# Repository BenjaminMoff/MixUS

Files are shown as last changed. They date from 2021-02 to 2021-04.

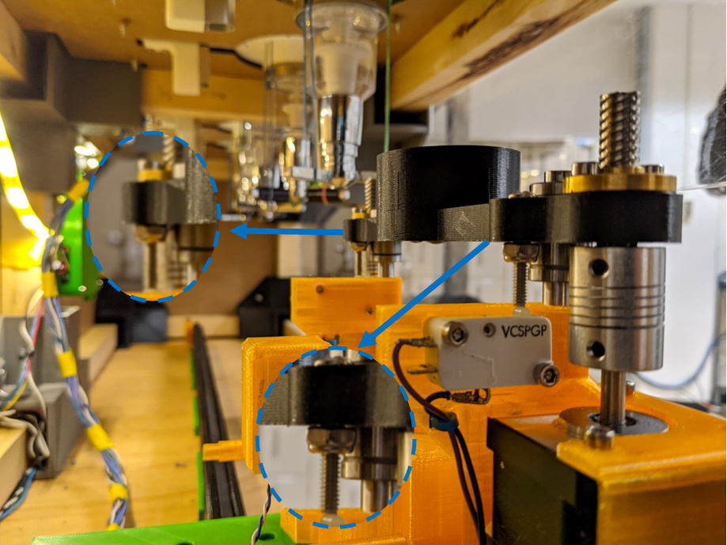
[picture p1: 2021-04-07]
Media Wiki/XYZ Assembly/Assembly Picture/Z_Pusher_Adjustement_Screw.png

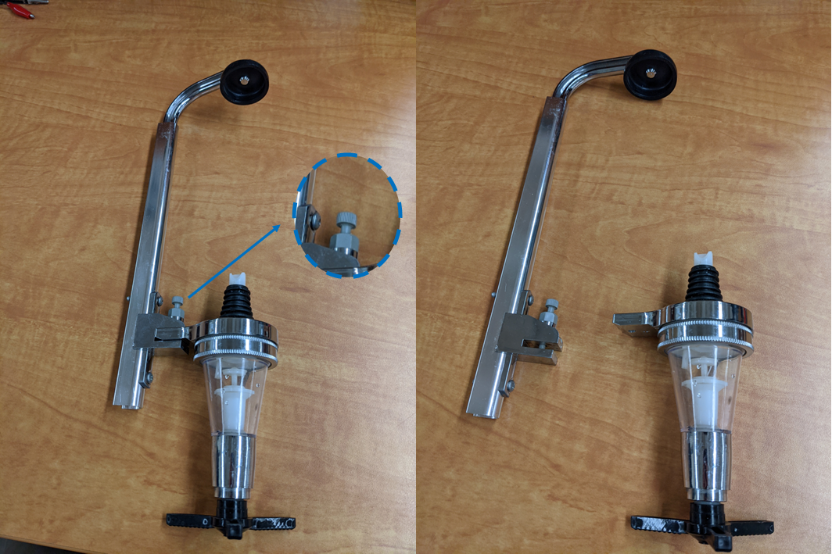
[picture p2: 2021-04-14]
Media Wiki/Frame Assembly/Assembly picture/Dispenser_1.png

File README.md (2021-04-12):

# MixUS
<p align="center">
  animated
  animated
  
  animated
</p>

From left to right : Laurent Tétreault, Yohan Bélanger, Félix Richard, Benjamin Moffett & Raphaël Cloutier
## Software License GNU GPL
MixUS is an open source project that uses the GNU GPL v3 license. This license is used since PyQt5, the framework that the app is built on, is also GNU GPL v3.

1. Anyone can copy, modify and distribute this software.
2. You have to include the license and copyright notice with each and every distribution.
3. You can use this software privately.
4. You can use this software for commercial purposes.
5. If you build your business solely from this code, you need to open-source the whole code base.
6. If you modify it, you have to indicate changes made to the code.
7. Any modifications of this code base MUST be distributed with the same license, GPLv3.
8. This software is provided without warranty.
9. The software author or license can not be held liable for any damages inflicted by the software.

More information about this license can be found [here](https://gist.github.com/kn9ts/cbe95340d29fc1aaeaa5dd5c059d2e60)

## Material License CC BY-SA
MixUS uses cads found in the [Open Build catalog](https://openbuildspartstore.com/). Thus, the material license for this project is the Creative Commons Attribution-ShareAlike 4.0 International (CC BY-SA). 
Under this license, you are free to:
- Share: copy and redistribute the material in any medium or format
- Adapt: remix, transform, and build upon the material for any purpose, even commercially.

Under the following terms:
- Attribution: You must give appropriate credit, provide a link to the license, and indicate if changes were made. You may do so in any reasonable manner, but not in any way that suggests the licensor endorses you or your use.
- ShareAlike: If you remix, transform, or build upon the material, you must distribute your contributions under the same license as the original.

More information about this license can be found [here](https://creativecommons.org/licenses/by-sa/4.0/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)

## Mechanical Assembly
All the information for mechanical assembly can be found in [this wiki](https://github.com/BenjaminMoff/MixUS/wiki).
## Software

### Raspberry Pi Setup
If you chose to use a Raspberry Pi, you can run [this file](https://github.com/BenjaminMoff/MixUS/blob/main/configuration/PiConfig.sh) to automagically download Python, compile it, and get all the required packages.

If you are using the same 7" touch screen that we are (see the bom for the exact screen), you need to change the following in the Raspberry Pi's config.txt file:
- max_usb_curren=1
- hdmi_force_hotplug=1
- config_hdmi_boost=7
- hdmi_group=2
- hdmi_mode=87
- hdmi_drive=1
- display_rotate=0
- hdmi_cvt 1024 600 60 6 0 0 0

### Windows Setup
If you chose to use a Windows computer, you need to have a version of Python 3 installed. Then, you can run [this file](https://github.com/BenjaminMoff/MixUS/blob/main/configuration/Pythonconfig.bat) to automagically download the required packages.

The Windows version of the app cannot support the detection of the cup since it is done using a limit switch connected to a Raspberry Pi.

### Change the database
The app uses a database to remember all the drinks you like and the bottles you have. You can add more drinks to the database by running, in the terminal from MixUS/code/, this command: 
- Windows: py DrinkDatabaseUpdater.py
- Raspbian: python3 DrinkDatabaseUpdater.py

### Run MixUS
To run the application, you need to run the following command in the terminal from MixUS/code/:
- Windows: py Mixus.py
- Raspbian: python3 Mixus.py

### Documentation
The entire documentation for the code can be found [here](https://htmlpreview.github.io/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).

## Special thanks to
Société des Alcools du Québec for providing the pictures used in the app. All of the pictures are their property and shall not be used for any other purpose other than recreating this project.

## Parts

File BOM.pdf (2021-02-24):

Mecanic BOM: 100XXX
No | Piece | Description
100001 | SUPPORTROUEY | Printed support of the y wheel
100002 | M 5X16MM SCREW | M5 X16 mm screw
100003 | 608Z BALL BEARING | 608ZZ ball bearing
100004 | M5 NUT | M5 nut
100005 | SUPPORTMOTEURZ | Printed support of the z motor
100006 | NEMA17 | Stepper motor NEMA 17
100007 | 5T08MM COUPLER | 5T 08 mm coupler
100008 | LIMITSWITCH | Limit switch
100009 | LEADSCREW | Lead screw
100010 | 8MM ROD | 8mm rod
100011 | M3 X 12MM SCREW | m3 X 12mm screw
100012 | M3 INSERT | M3 insert
100013 | IDLERX_PLATE | Idlerx plate
100014 | MOTOX_PLATE | Motox plate
100015 | GT2 MOTOR PULLEY | Gt2 Motor pulley
100016 | POULIE | Pulley
100017 | 20X40 EXTRUSION | 20x40cm printed extrude
100018 | CARRIAGEX | Carriage of the x motor
100019 | V-SLOT WHEEL | v-slot wheel
100020 | 6-32 X 1'' SCREW | 6-32 X 1'' screw
100021 | 6-32 LOCKNUT | 6-32 locknut
100022 | RAILY | Rail for the y movement
100023 | SPACER | Spacer
100024 | SUPPORTVERRE | Printed glass support
100025 | CHARIOT V2 | Printed cart for the glass
100026 | RAIL | Printed rail for the z movement
100026 | MIDDLE MODDED EXTRUSION | Printed extrusion in center
100026 | MODDED EXTRUSION MOTORSIDE | Printed extrusion on motor side
100026 | MODDED EXTRUSION PULLEYSIDE | Printed extrusion on pulley side
100026 | PUSHER | Pusher
100026 | LEADSCREW NUT | Leadscrew nut
100026 | LM8 UU | LM8UU

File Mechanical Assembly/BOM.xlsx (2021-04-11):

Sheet: V1
Mecanic BOM: 100XXX
No | Piece | Description
100001 | SUPPORTROUEY | Printed support of the y wheel
100002 | M 5X16MM SCREW | M5 X16 mm screw
100003 | 608Z BALL BEARING | 608ZZ ball bearing
100004 | M5 NUT | M5 nut
100005 | SUPPORTMOTEURZ | Printed support of the z motor
100006 | NEMA17 | Stepper motor NEMA 17
100007 | 5T08MM COUPLER | 5T 08 mm coupler
100008 | LIMITSWITCH | Limit switch
100009 | LEADSCREW | Lead screw
100010 | 8MM ROD | 8mm rod
100011 | M3 X 12MM SCREW | m3 X 12mm screw
100012 | M3 INSERT | M3 insert
100013 | IDLERX_PLATE | Idlerx plate
100014 | MOTOX_PLATE | Motox plate
100015 | GT2 MOTOR PULLEY | Gt2 Motor pulley
100016 | POULIE | Pulley
100017 | 20X40 EXTRUSION | 20x40cm printed extrude
100018 | CARRIAGEX | Carriage of the x motor
100019 | V-SLOT WHEEL | v-slot wheel
100020 | 6-32 X 1'' SCREW | 6-32 X 1'' screw
100021 | 6-32 LOCKNUT | 6-32 locknut
100022 | RAILY | Rail for the y movement
100023 | SPACER | Spacer
100024 | SUPPORTVERRE | Printed glass support
100025 | CHARIOT V2 | Printed cart for the glass
100026 | RAIL | Printed rail for the z movement
100026 | MIDDLE MODDED EXTRUSION | Printed extrusion in center
100026 | MODDED EXTRUSION MOTORSIDE | Printed extrusion on motor side
100026 | MODDED EXTRUSION PULLEYSIDE | Printed extrusion on pulley side
100026 | PUSHER | Pusher
100026 | LEADSCREW NUT | Leadscrew nut
100026 | LM8 UU | LM8UU

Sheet: V2
Printed parts |  |  |  |  |  | Fasteners
Section | Component | Configuration | Qty | Printing support |  | Section | Component | Qty | CAD Link | Where to buy
X Axis | X_Bracket_Wire | Default | 1 | No |  | Inserts | M2.5x3.4mm_insert | 20 | McMaster (https://www.mcmaster.com/94180A321/~)
 | X_Carriage | Default | 1 | Touching build plate only |  |  | M3x6mm_insert | 150 | GrabCAD (https://grabcad.com/library/fitsco-heatfit-range-brass-threaded-insert-for-plastic-1/details?folder_id=1381689) | Amazon.ca (https://www.amazon.ca/gp/product/B087N4LVD1/ref=ppx_yo_dt_b_asin_title_o00_s02?ie=UTF8&psc=1)
 | X_Idler_plate | Default | 1 | No |  | Nuts | 6_32_locknut | 16 | McMaster (https://www.mcmaster.com/90631A007/)
 | X_Motor_plate | Default | 1 | No |  |  | M5_Nut | 3 | McMaster (https://www.mcmaster.com/90591A260/~)
 | X_V_Wheel_spacer | Default | 4 | No |  |  | 0,1875po_Nut | 28 | N/A | renodepot.com (https://www.renodepot.com/fr/boulon-de-poele-63867995)
Y Axis | Y_Carriage | Default | 1 | No |  | Screws | 6_32_screw | 16 | McMaster (https://www.mcmaster.com/91772A153/~)
 | Y_Pinion | Default | 1 | No |  |  | M2.5x6mm_screw | 20 | McMaster
 | Y_rack | Default | 1 | No |  |  | M3x12mm_screw | 150 | McMaster
 | Y_rail | Default | 1 | No |  |  | M5x16mm_screw | 3 | McMaster
 | Y_Support_rail | Default | 1 | Yes |  |  | 0,1875x0,5po_Screw | 28 | N/A | renodepot.com (https://www.renodepot.com/fr/boulon-de-poele-63867995)
 | Y_Glass_holder | Default | 1 | Yes |  |  | No6x1,25po_Wood_Screw | 78 | McMaster (https://www.mcmaster.com/90610A719/)
 | Y_Extern_slider_support | Default | 1 | No |  |  | No12x1,25po_Wood_Screw | 24 | McMaster (https://www.mcmaster.com/92470A298/)
 | Y_Glass_Holder_Slider | Default | 1 | No
 | Y_Glass_Holder_Rod_Stopper | Default | 2 | No
 | Y_Glass_Holder_Rod | Default | 2 | No
 | Y_Switch_Bracket | Default | 1 | No
 | Y_Wheel_bracket | Default | 1 | Touching build plate only
 |  | Symmetry | 1 |  |  | Electronic
Z Axis | Z_Motor_Bracket | Default | 1 | Touching build plate only
 |  | Symmetry | 1 |  |  | Section | Component | Qty | CAD Link | Where to buy
 | Z_Pusher | Default | 1 | No |  | Proto PCB | 4x6cm_ProtoBoard | 1 | GrabCAD (https://grabcad.com/library/prototyping-breadboard-1) | Amazon.ca (https://www.amazon.ca/-/fr/Eiechip%C2%AE-prototype-universel-circuit-%C3%A9lectronique/dp/B07MTBNX8F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)
2040 printable extrusion | 2040_Printable_extrusion | Center | 3 | Yes | https://openbuilds.com/ |  | Extra_long_male_header_pin | 22 | N/A | Adafruit.com (https://www.adafruit.com/product/400)
 |  | Side | 2 |  |  | X, Y, Z Axis | LimitSwitch | 5 | GrabCAD (https://grabcad.com/library/limit-switch-6) | Amazon.ca (https://www.amazon.ca/Twidec-Switch-Roller-Arduino-V-156-1C25/dp/B07NVD5LGM)
 | 2040_Connector_Extrusion | M2.5 Slot | 8 | No |  |  | Nema17 | 4 | GrabCAD (https://grabcad.com/library/nema-17-stepper-motor-27) | Amazon.ca (https://www.amazon.ca/-/fr/SIMAX3D-Moteur-phases-imprimante-extrudeuse/dp/B0857489JD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)
 |  | M3 Top Slot | 4 | No |  | Wiring | Wire 22awg (Limit switch cup,Z) (200mm) | 6 | N/A | N/A
 |  | M3 slot | 8 | No |  |  | Wire 22awg (1m) | 26 | N/A | N/A
Rambo case | Rambo_Case_Top | Default | 1 | No |  |  | Wire 22 awg (1.5m) (extension to Pi) | 2 | N/A | N/A
 | Rambo_Case_Bottom | Default | 1 | Yes |  |  | Male dupont connector pin | 26 | N/A | Amazon.ca
Bottle Supports | BottleSup_Adapter | Default | 6 | Yes |  |  | Male dupont connector socket | 24 | N/A
 | BottleSup_Lock | Default | 24 | No |  |  | Female dupont connector pin | 2 | N/A
 | BottleSup_Removable_Plate_A | Default | 6 | Yes |  | Control | 7'' touch screen | 1 | N/A | Amazon.ca (https://www.amazon.ca/-/fr/Longruner-Raspberry-tactile-syst%C3%A8mes-protection/dp/B07RZZW8W1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)
 | BottleSup_Removable_Plate_B | Default | 6 | Yes |  |  | Raspberry pi 4 | 1 | N/A | CanaKit.com (https://www.canakit.com/raspberry-pi-4-2gb.html?cid=cad&src=raspberrypi)
Frame | Frame_Bottom_Center_Beam_Bracket | Plexi side | 1 | No |  |  | Rambo_board | 1 | GrabCAD (https://grabcad.com/library/reprap-electo-rambo-3d-printer-board-1-3-1) | Ultimachine (https://ultimachine.com/products/rambo-1-3)
 |  | Wood side | 1 | No |  |  | 40x40x10_DC_Fan | 1 | GrabCAD (https://grabcad.com/library/40mm-dc-fan-1) | Amazon.ca (https://www.amazon.ca/-/fr/Noctua-Ventilateur-silencieux-NF-A4x10-FLX/dp/B009NQLT0M)
 | Frame_Top_Center_Beam_Bracket | Plexi side | 1 | No
 |  | Wood side | 1 | No
 | Frame_Corner_Plexi_Side | Default | 1 | No
 |  | Symmetry | 1 | No
 | Frame_Corner_Wood_Side | Default | 1 | No |  | Others
 |  | Symmetry | 1 | No
 |  |  |  |  |  | Section | Part | Qty | CAD Link | Where to buy
 |  |  |  |  |  | Z Axis | 5_to_8_mm_coupler | 2 | GrabCAD (https://grabcad.com/library/nema-17-coupler-1) | Spool3D.ca (https://spool3d.ca/flexible-coupling-5mm-to-8mm/)
wood + acrylic |  |  |  |  |  |  | 8mm_38.5mm_leadscrew | 2 | GrabCAD (https://grabcad.com/library/8mm-lead-screw-with-nut-1) | Spool3D.ca (https://spool3d.ca/lead-screw-8mm-2mm-pitch-8mm-lead/)
 |  |  |  |  |  |  | 8mm_leadscrew_nut | 2 | GrabCAD (https://grabcad.com/library/8mm-lead-screw-with-nut-1) | Spool3D.ca (https://spool3d.ca/t8-lead-screw-nut/)
 | Specifications | qty | Where to buy |  |  |  | 8mm_50mm_rod | 2 | N/A | Spool3D.ca (https://spool3d.ca/straight-rod-8mm/)
2po x 2po wood beam | 532.4 mm | 8 | renodepot.com (https://www.renodepot.com/fr/pin-blanc-2-po-x-2-po-x-8-pi-8670092) |  |  |  | LM8UU_linear_bearing | 2 | GrabCAD (https://grabcad.com/library/lm8uu-others-1~) | Spool3D.ca (https://spool3d.ca/lm8uu-linear-bearing/)
 | 227 mm | 6 |  |  |  |  | Rubber band (wall = 1mm, width = 1.2 mm, flat length = 65 mm) | 18 | N/A | Bureauengros.com (https://www.bureauengros.com/products/13552-fr-staples-bandes-elastiques-economiques-tailles-et-couleurs-variees)
 | 250 mm | 5 |  |  |  | X Axis | GT2_pulley | 1 | GrabCAD (https://grabcad.com/library/pulley-gt2-20t-b5-1) | Spool3D.ca (https://spool3d.ca/20-tooth-gt2-pulley-for-hnbr-high-temperature-belt)
2 ft x 4 ft x 1/4 po masonite | N/A | 6 | renodepot.com (https://www.renodepot.com/fr/panneau-de-masonite-afa-regulier-1-4-x-2-x-4-75215204-8914017) |  |  |  | Idler_pulley | 1 | N/A | SeeMeCNC (https://www.seemecnc.com/collections/parts-accessories/products/r4-idler-bearing-cover-9-pack)
 |  |  |  |  |  |  | 608zz_ball_bearing | 2 | N/A | Spool3D.ca (https://spool3d.ca/608zz-bearing/~)
 |  |  |  |  |  |  | Vslot_wheel | 4 | N/A | Spool3D.ca (https://spool3d.ca/solid-v-slot-wheel-pom/)
410mm x 620 mm x 3.3 mm acrylic | N/A | 2 | renodepot.com (https://www.renodepot.com/fr/em-plastic-panneau-en-acrylique-3-mm-18-x-36-blanc-49085-55375025) |  |  | Others | Dispenser | 6 | GrabCAD (https://grabcad.com/library/shot-dispenser-1) | Amazon.ca (https://www.amazon.ca/-/fr/Distributeur-rotatif-liqueur-bouteilles-FTA1814/dp/B005BYWYHW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)
 |  |  |  |  |  |  | Red_cup | 1 | N/A | Costco (https://www.costco.ca/kirkland-signature-the-big-red-cup-heavyweight-18-oz.-plastic-cold-cups%2C-240-count.product.100484805.html)
 |  |  |  |  |  | Y Axis | 8x3mm_magnet | 8 | N/A | Amazon.ca (https://www.amazon.ca/Wukong-Magnets-Magnetic-Circular-magnet-108/dp/B07GTM383S)

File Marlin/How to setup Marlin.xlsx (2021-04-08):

If you don't have the same hardware (stepper motor, stepper driver, belt, etc.), use this excel sheet to calculate your specific step/mm for each axis
Informations about your specific setup are highlight in blue. Where you can find these informations are highlight in yellow. Informations that you need to put in your Marlin configuration are highlight in green
Information | Where to find ? | Value
Number of step per revolution | Stepper data sheet | 200
Stepper driver microstep (in fraction) | Stepper driver data sheet | 0.0625
 |  |  |  |  | To update Marlin :
X Axis |  |  | step/mm X : | 80 | 1. Open « configuration.h » in your Marlin folder
Belt pitch (mm) | Belt data sheet | 2 |  |  | 2. Seach (ctrl-F) « DEFAULT_AXIS_STEPS_PER_UNIT »
Pulley number of teeth | Count it or data sheet | 20 |  |  | 3. Replace « step X », « step Y » and « step Z » from the picture below with your calulate value (green)
Y Axis |  |  | step/mm Y : | 21.22065908
Modulus gear | CAD | 3
Number of teeth of the gear | CAD | 16
Pitch Y |  | 9.425
Z Axis
Leadscrew pitch (mm) | leadscrew data sheet | 8 | step/mm Z : | 400

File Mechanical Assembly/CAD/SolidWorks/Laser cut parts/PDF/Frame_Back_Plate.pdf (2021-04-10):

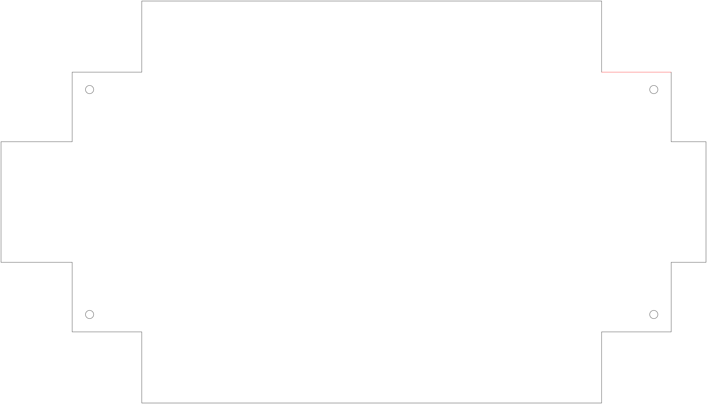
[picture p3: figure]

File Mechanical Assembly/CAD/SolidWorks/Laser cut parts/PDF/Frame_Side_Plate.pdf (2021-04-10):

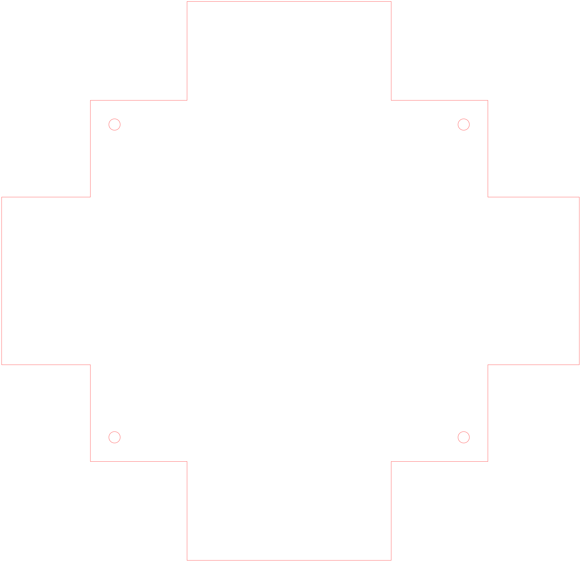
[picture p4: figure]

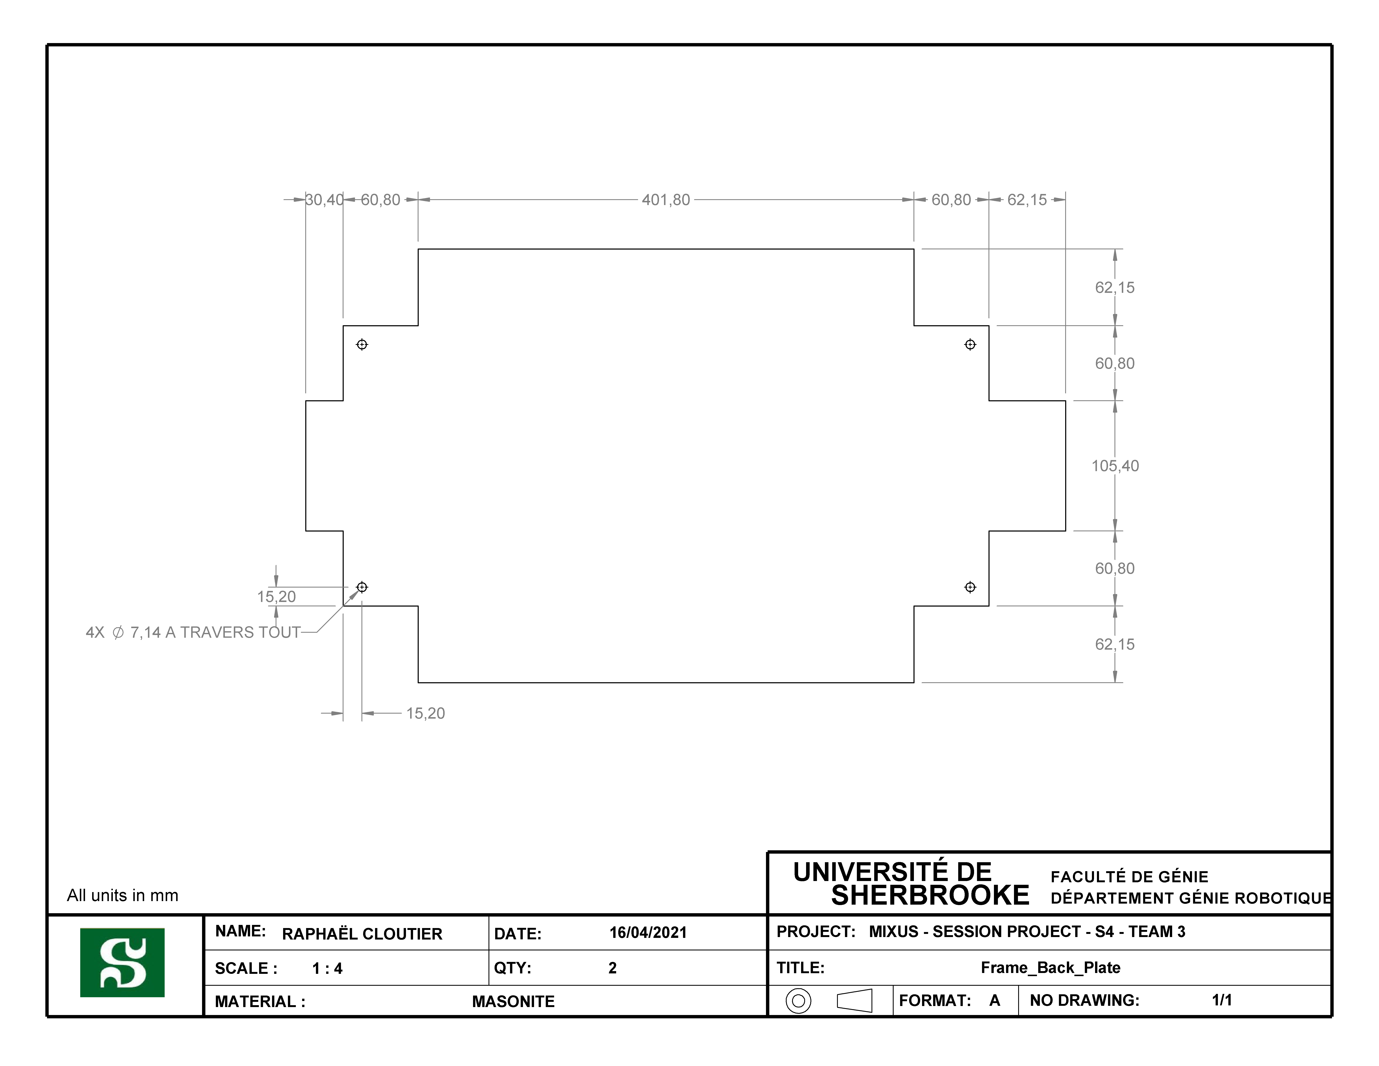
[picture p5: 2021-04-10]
Mechanical Assembly/CAD/SolidWorks/Frame materials/Drawing/PNG/Drawing_Frame_Back_Plate.PNG

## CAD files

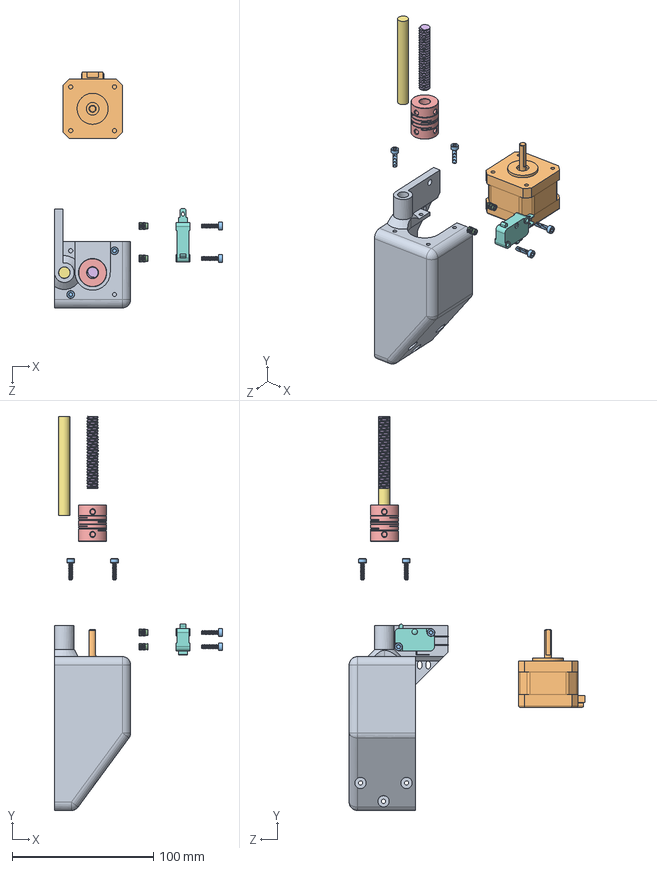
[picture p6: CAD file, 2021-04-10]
Mechanical Assembly/CAD/SolidWorks/Assembly/Sub_assembly/SubAss_Z_Motor_Bracket.SLDASM
119.0 x 279.0 x 167.0 mm
Z_Motor_bracket
Nema17
M3x12mm_screw x 4
M3x6mm_insert x 2
5_to_8_mm_coupler
8mm_leadscrew
8mm_rod
LimitSwitch

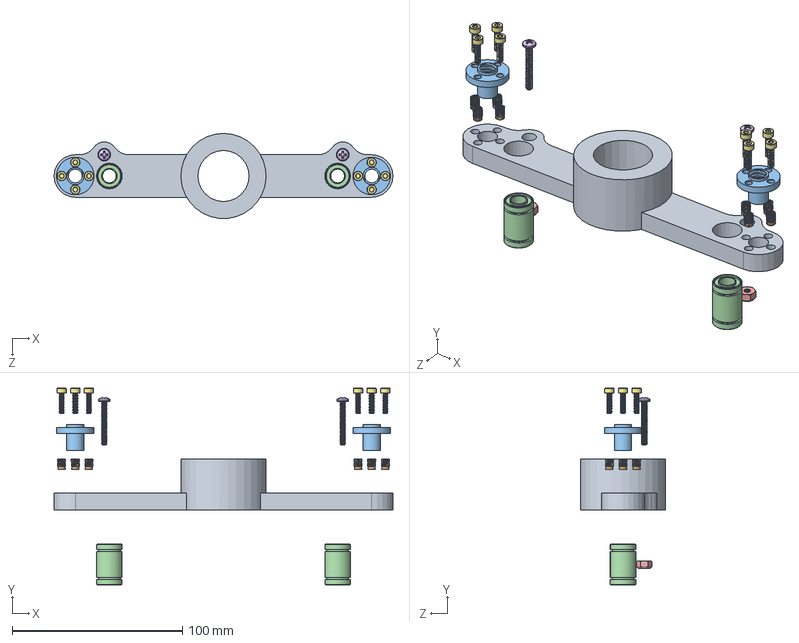
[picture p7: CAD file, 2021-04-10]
Mechanical Assembly/CAD/SolidWorks/Assembly/Sub_assembly/SubAss_Z_Pusher.SLDASM
199.0 x 115.5 x 50.0 mm
Z_Pusher
M3x6mm_insert x 8
8mm_leadscrew_nut x 2
LM8UU_linear_bearing x 2
6_32_locknut x 2
6_32_screw x 2
M3x12mm_screw x 8

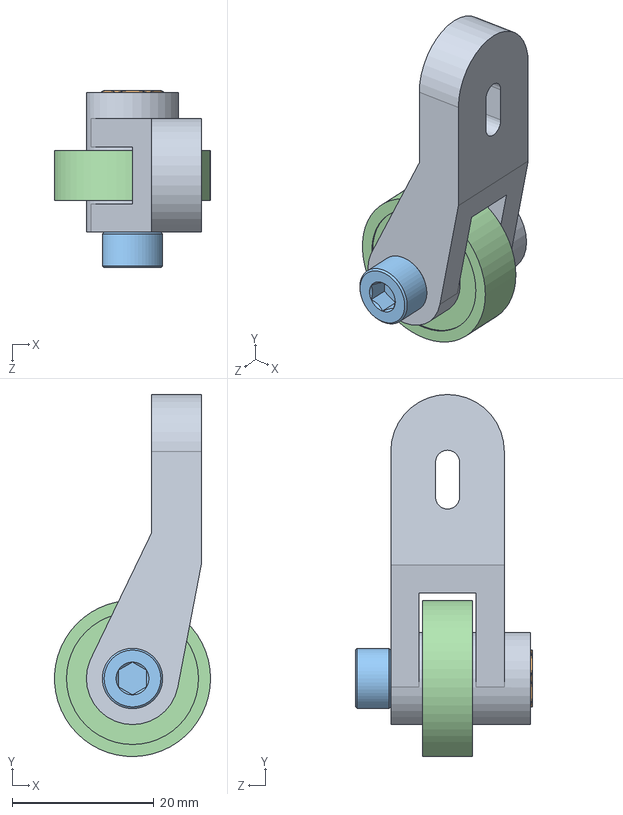
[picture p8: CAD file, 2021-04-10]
Mechanical Assembly/CAD/SolidWorks/Assembly/Sub_assembly/SubAss_Y_Wheel_Bracket.SLDASM
22.0 x 51.0 x 25.0 mm
Y_Wheel_bracket
M5_nut
M5x16mm_screw
608zz_ball_bearing

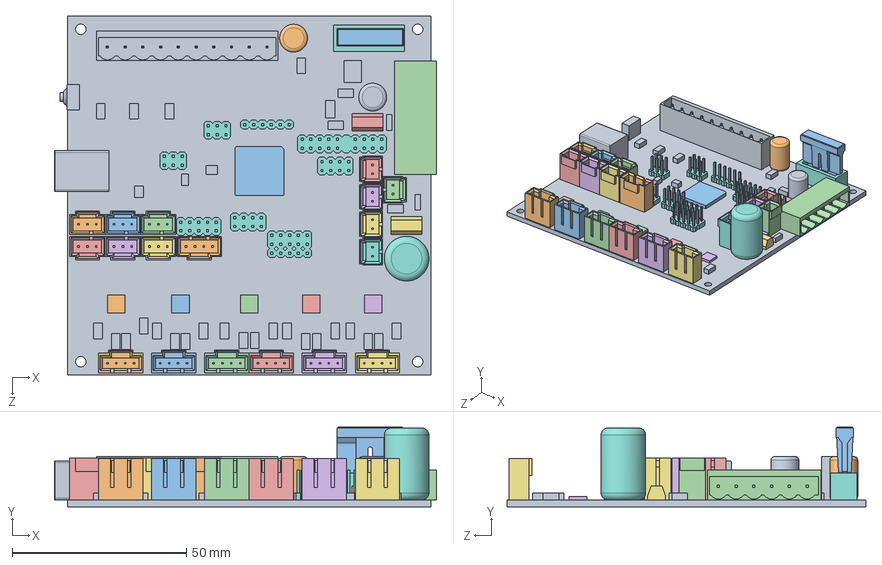
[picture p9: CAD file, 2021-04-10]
Mechanical Assembly/CAD/SolidWorks/Electronic/Rambo_board.SLDASM
109.6 x 22.8 x 102.9 mm
pcb.stp
X-stepper.stp
Y-stepper.stp
Z-stepper.stp
Z-stepper2.stp
Extruder 0.stp
Extruder 1.stp
C76.stp
Heaters & Fans.stp
X-Min.stp
Y-Min.stp
Z-Min.stp
X-Max.stp
Y-Max.stp
Z-Max.stp
Fuse F4.stp
USB.stp
I2C.stp
ATMEGA2560.stp
Power.stp
T0.stp
T1.stp
T2.stp
T3.stp
Reset.stp
X driver.stp
Y driver.stp
Z driver.stp
E0 driver.stp
E1 driver.stp
Fuse F2.stp
Pins.stp
C65.stp
C 65.stp
Fuse.stp
Contact.stp
Fuse F3.stp

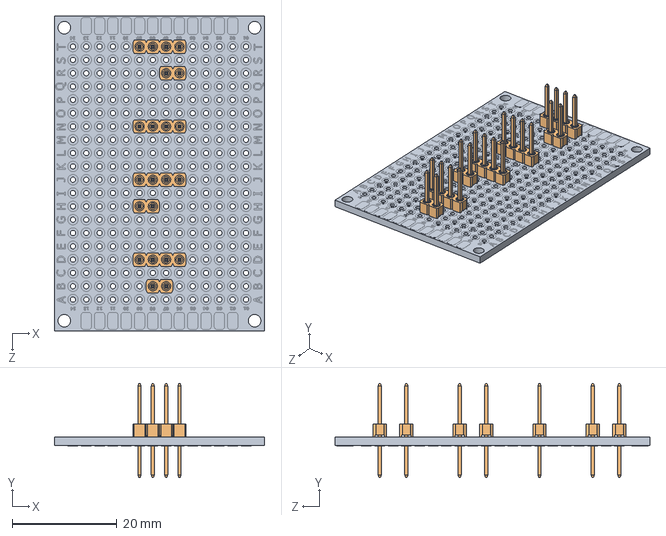
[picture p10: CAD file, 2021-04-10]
Mechanical Assembly/CAD/SolidWorks/Assembly/Sub_assembly/SubAss_X_Connector_Plate.SLDASM
40.1 x 18.0 x 60.1 mm
4x6cm_ProtoBoard
Extra_long_male_header_pin x 7

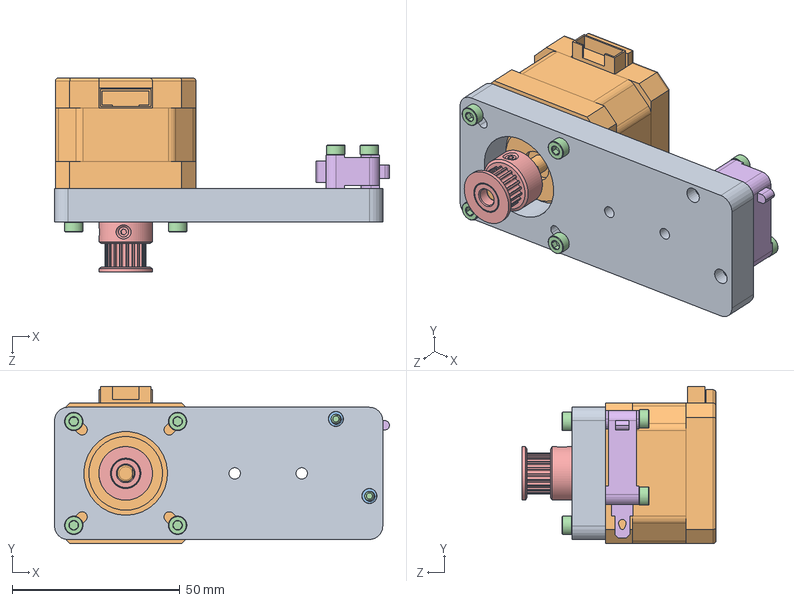
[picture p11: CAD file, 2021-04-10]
Mechanical Assembly/CAD/SolidWorks/Assembly/Sub_assembly/SubAss_X_Motor_Plate.SLDASM
100.0 x 47.0 x 58.0 mm
X_Motor_plate
Nema17
M3x6mm_insert x 2
M3x12mm_screw x 6
GT2_pulley
LimitSwitch

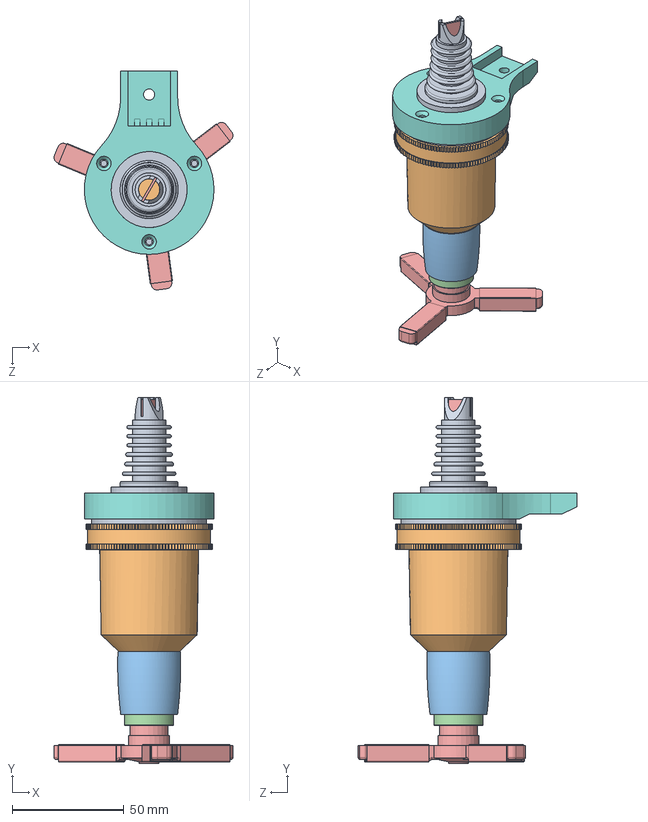
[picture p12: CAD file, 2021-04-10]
Mechanical Assembly/CAD/SolidWorks/Others/Dispenser.SLDASM
80.0 x 163.7 x 97.9 mm
Canister Filler.stp
Canister.stp
Float Inner.stp
Float Seal.stp
Flow Splitter.stp
Internal Spout.stp
Internal Support.stp
Seal.stp
Tightening Ring.stp
Pour Guide.stp
Pour Button.stp
Push Bars.stp
Spout.stp

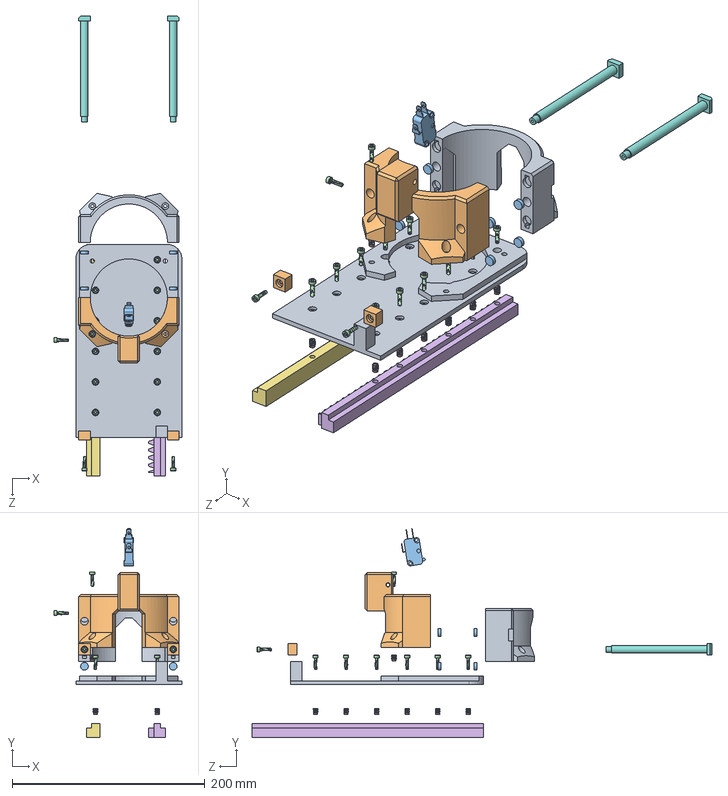
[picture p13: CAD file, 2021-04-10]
Mechanical Assembly/CAD/SolidWorks/Assembly/Sub_assembly/SubAss_Y_Carriage.SLDASM
132.6 x 216.7 x 476.8 mm
Y_Carriage
Y_Glass_holder
LimitSwitch
M3x12mm_screw x 15
M3x6mm_insert x 12
Y_Rack
Y_Rail
Y_Glass_Holder_Rod x 2
Y_Glass_Holder_Slider
Y_Glass_Holder_Rod_Stopper x 2
8x3mm_Magnet x 8

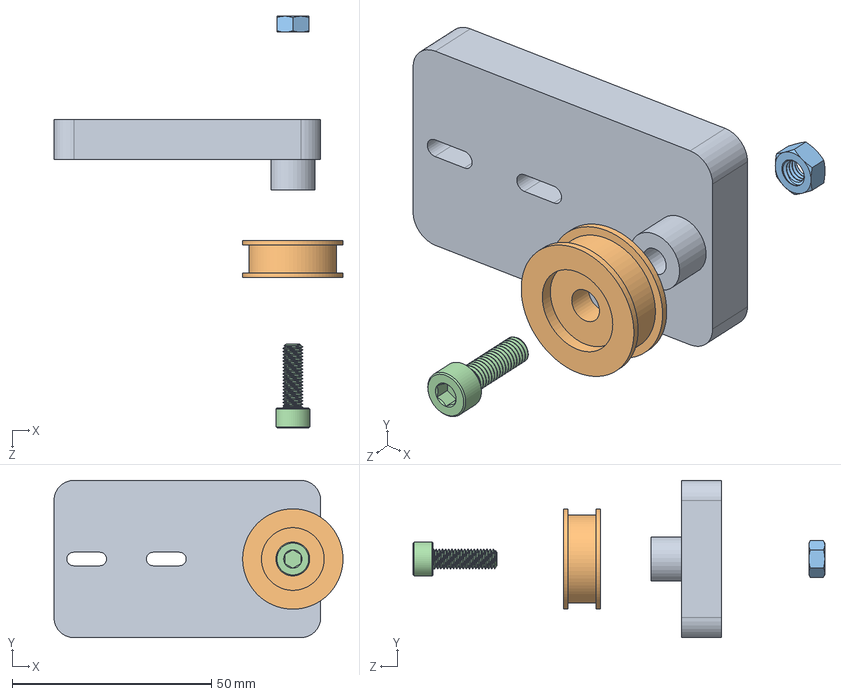
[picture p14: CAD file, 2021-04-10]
Mechanical Assembly/CAD/SolidWorks/Assembly/Sub_assembly/SubAss_X_Idler_Plate.SLDASM
72.6 x 39.5 x 103.4 mm
X_Idler_plate
Idler_pulley
M5_nut
M5x16mm_screw

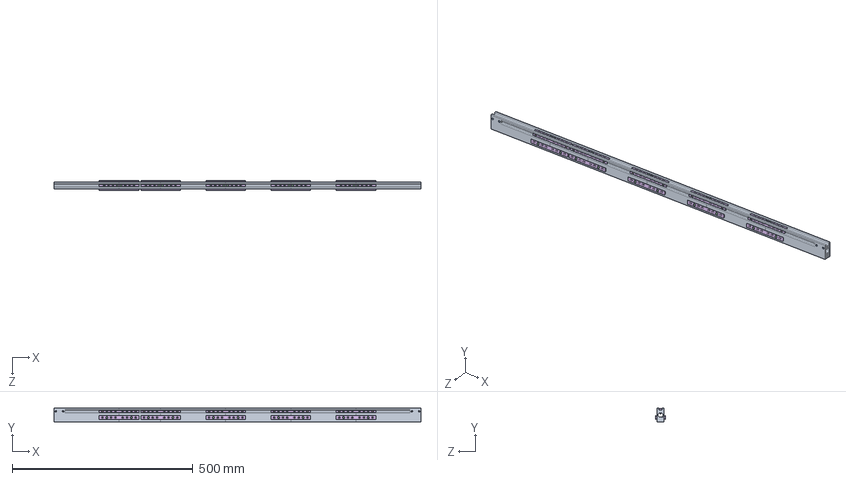
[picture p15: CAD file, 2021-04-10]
Mechanical Assembly/CAD/SolidWorks/Assembly/Sub_assembly/SubAss_2040_Extrusion.SLDASM
1015.0 x 40.0 x 28.4 mm
2040_Printable_extrusion x 6
M2.5x3.4mm_insert x 20
M3x6mm_insert x 58
M3x12mm_screw x 30
M2.5x6mm_screw x 20
2040_Connector_Extrusion x 25

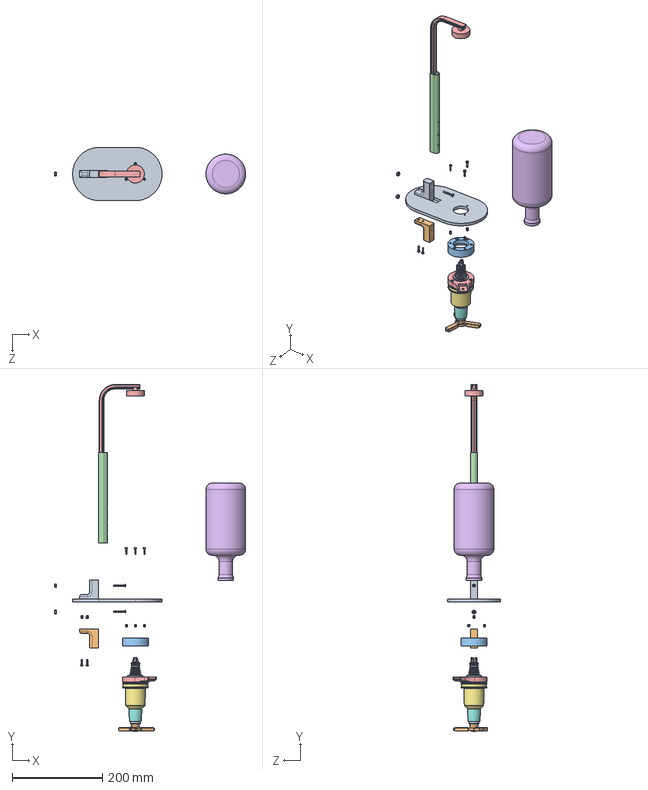
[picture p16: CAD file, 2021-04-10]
Mechanical Assembly/CAD/SolidWorks/Assembly/Sub_assembly/SubAss_Removable_Bottle_Support.SLDASM
423.4 x 767.6 x 118.0 mm
BottleSup_Removable_Plate_A
BottleSup_Removable_Plate_B
BottleSup_Adapter
M3x6mm_insert x 5
M3x12mm_screw x 5
Canister Filler.stp
Canister.stp
Float Inner.stp
Float Seal.stp
Flow Splitter.stp
Internal Spout.stp
Internal Support.stp
Seal.stp
Tightening Ring.stp
Pour Guide.stp
Pour Button.stp
Push Bars.stp
Spout.stp
Bottle_Support_TubeA
Bottle_Support_TubeB
Bottle
6_32_screw x 2
6_32_locknut x 2

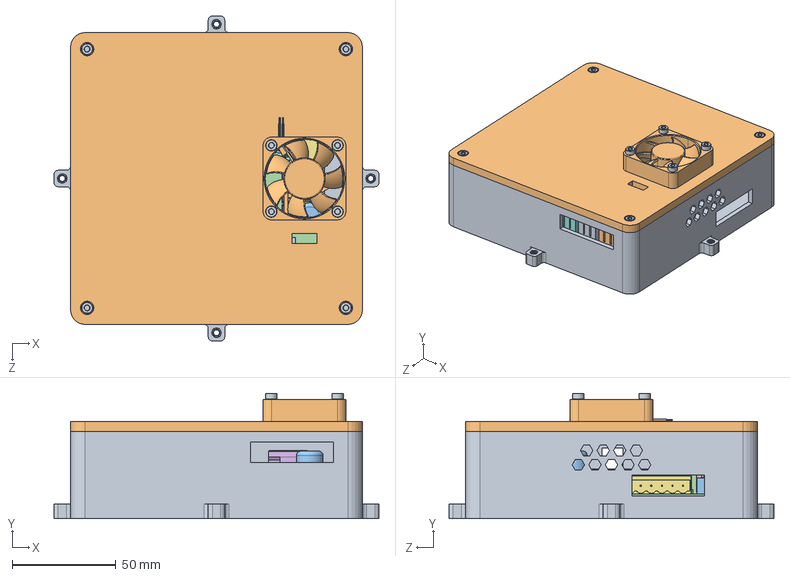
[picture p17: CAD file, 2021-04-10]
Mechanical Assembly/CAD/SolidWorks/Assembly/Sub_assembly/SubAss_Rambo_Case.SLDASM
157.0 x 60.5 x 157.0 mm
Rambo_Case_Bottom
Rambo_Case_Top
M3x6mm_insert x 12
pcb.stp
X-stepper.stp
Y-stepper.stp
Z-stepper.stp
Z-stepper2.stp
Extruder 0.stp
Extruder 1.stp
C76.stp
Heaters & Fans.stp
X-Min.stp
Y-Min.stp
Z-Min.stp
X-Max.stp
Y-Max.stp
Z-Max.stp
Fuse F4.stp
USB.stp
I2C.stp
ATMEGA2560.stp
Power.stp
T0.stp
T1.stp
T2.stp
T3.stp
Reset.stp
X driver.stp
Y driver.stp
Z driver.stp
E0 driver.stp
E1 driver.stp
Fuse F2.stp
Pins.stp
C65.stp
C 65.stp
Fuse.stp
Contact.stp
Fuse F3.stp
M3x12mm_screw x 12
40x40x10_DC_Fan

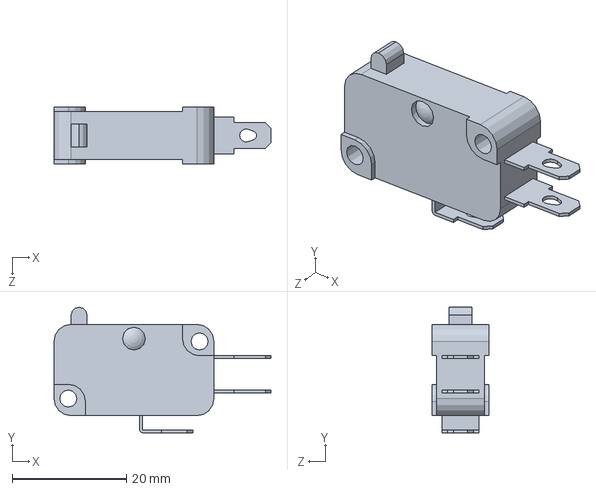
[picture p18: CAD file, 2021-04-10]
Mechanical Assembly/CAD/SolidWorks/Electronic/LimitSwitch.SLDPRT
38.0 x 22.0 x 10.0 mm

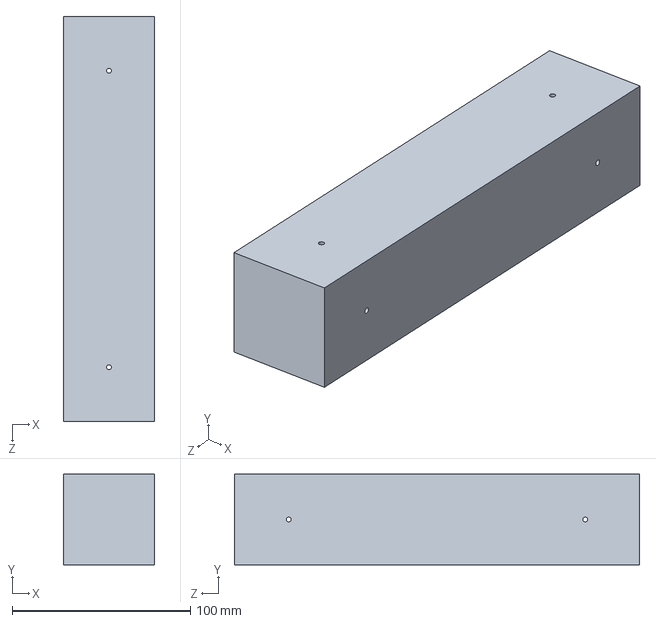
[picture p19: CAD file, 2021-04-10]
Mechanical Assembly/CAD/SolidWorks/Frame materials/Frame_Wood_Beam.SLDPRT
50.8 x 50.8 x 227.0 mm

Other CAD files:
Mechanical Assembly/CAD/SolidWorks/Insert/M2.5x3.4mm_insert.SLDPRT
Mechanical Assembly/CAD/SolidWorks/Laser cut parts/DXF/Frame_Acrylic_Right.DXF
Mechanical Assembly/CAD/SolidWorks/Laser cut parts/STL/Frame_Acrylic.SLDPRT
Mechanical Assembly/CAD/SolidWorks/Nut/6_32_locknut.SLDPRT
Mechanical Assembly/CAD/SolidWorks/Assembly/Exploded_view/SubAss_2040_Extrusion.SLDDRW
Mechanical Assembly/CAD/SolidWorks/Assembly/Exploded_view/SubAss_X_Connector_Plate.SLDDRW
Mechanical Assembly/CAD/SolidWorks/Assembly/Exploded_view/SubAss_X_Idler_Plate.SLDDRW
Mechanical Assembly/CAD/SolidWorks/Assembly/Exploded_view/SubAss_X_Motor_Plate.SLDDRW
Mechanical Assembly/CAD/SolidWorks/Assembly/Exploded_view/SubAss_Y_Carriage.SLDDRW
Mechanical Assembly/CAD/SolidWorks/Assembly/Exploded_view/SubAss_Y_Wheel_Bracket.SLDDRW
Mechanical Assembly/CAD/SolidWorks/Electronic/40x40x10_DC_Fan.SLDPRT
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

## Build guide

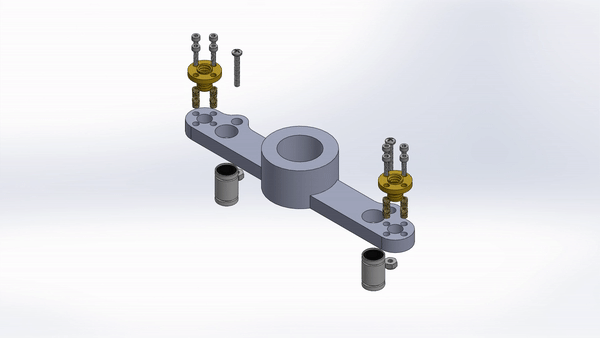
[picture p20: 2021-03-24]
Mechanical Assembly/CAD/SolidWorks/Assembly/Animation/GIF/SubAss_Z_Pusher.gif

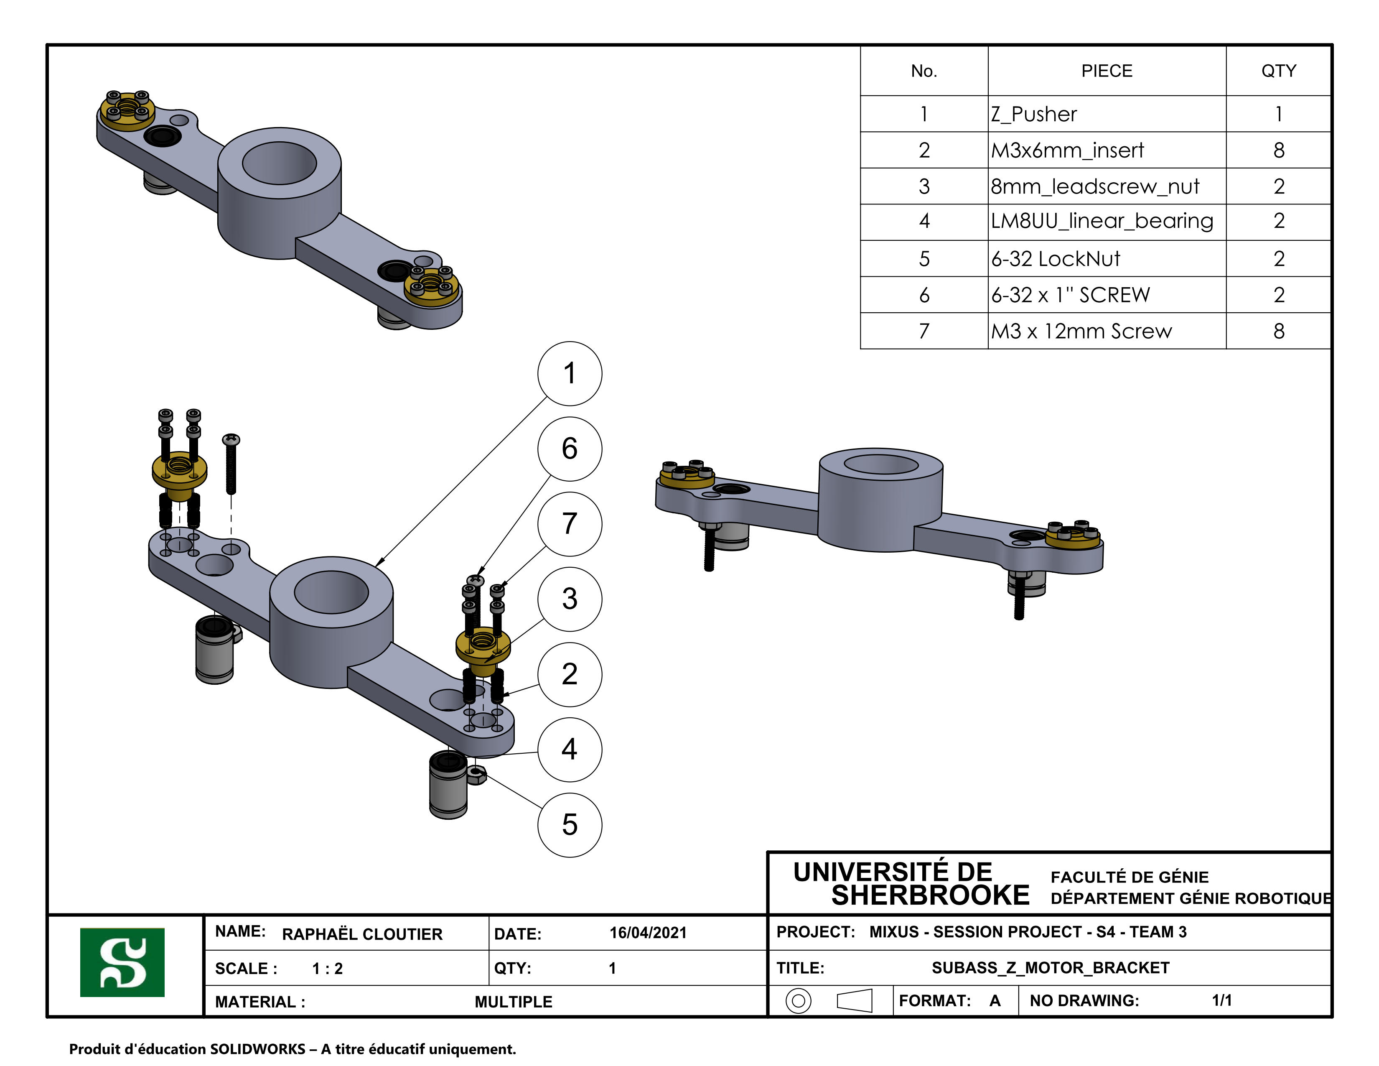
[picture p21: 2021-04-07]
Mechanical Assembly/CAD/SolidWorks/Assembly/Exploded_view/PNG/SubAss_Z_Pusher_01.png

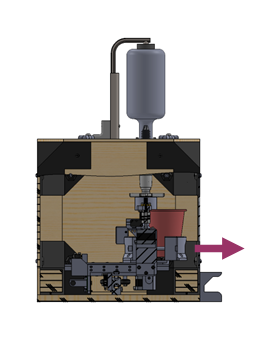
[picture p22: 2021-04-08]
Media Wiki/Putting it all together/Y_Wiring_Motor_Check.png

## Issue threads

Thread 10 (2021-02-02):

Algorithme de génération des g-codes

RichFel, 2021-02-02:
Génère les G-code selon le choix de drink de l'utilisateur.
- Recherche sur le fonctionnement d'un g-code
- Avoir les paramètres physiques de l'assemblage

Closed 2021-03-07.

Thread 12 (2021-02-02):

Menu Princpal - Interface

RichFel, 2021-02-02:
- Sélection de la boisson et transfert vers le menu boisson (Générer apparence en fonction de la boisson choisie)
- Bouton de transfert vers le menu de maintenance
- Bouton quit (fermer application et persistance des données)
- Apparence

Closed 2021-03-02.

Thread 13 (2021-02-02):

Menu boisson - Interface

RichFel, 2021-02-02:
- Interface modulaire pour affichage des différentes boissons choisies par l'utilisateur
- Modification de la boisson (double, sans alcool)
- Bouton lancement et transfert vers menu progression
- Bouton annuler et retour au menu principal

Closed 2021-03-05.

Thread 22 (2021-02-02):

Axe Y

raphclou, 2021-02-02:
Conception d'un système de roue dentée et crémaillère pour faire avancer le chariot
- Conception roue dentée
- Conception crémaillère
- Conception de « rails » pour le glissement du chariot
- Conception du support pour le maintient du moteur

Closed 2021-04-07.

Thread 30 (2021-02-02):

Conception du poussoir

raphclou, 2021-02-02:
- Doit avoir un trou pour laisser passer le liquide

- Trou pour bearing/leadscrew nut

- Rigide

Closed 2021-02-09.

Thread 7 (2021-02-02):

Programmer structure générale de l'interface

RichFel, 2021-02-02:
- Programmer l'interface de manière à démontrer que le Framework choisi permet de créer le produit voulu

RichFel, 2021-02-06:
Temps:
- 2x3 hrs sur Kivy
- 2x5 hrs sur PyQt5

Closed 2021-02-06.

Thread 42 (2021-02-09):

Test de la fixation entre les extrusions

BenjaminMoff, 2021-02-09:

Closed 2021-02-22.

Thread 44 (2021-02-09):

Test de la fixation des extrusions

BenjaminMoff, 2021-02-09:

Closed 2021-02-09.

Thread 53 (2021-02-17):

Choix et achat de l'interface

RichFel, 2021-02-17:
Faire la recherche pour acheter l'écran
Bonne option mais manque de documentation. J'ai contacté le vendeur pour qu'il m'en fournisse:
https://www.electromike.com/ecran-tactile-5-pouces-800x480-tft-ecran-lcd-interface-hdmi-touch-raspberry-pi-5scr.html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

Bonne option mais semble out of stock et la livraison peut prendre beaucoup de temps:
https://www.banggood.com/5-Inch-800-x-480-HD-TFT-LCD-Touch-Screen-For-Raspberry-PI-3-Model-B-or-2-Model-B-or-B+-or-A+-or-B-p-1054289.html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

Sinon amazon

Closed 2021-02-23.

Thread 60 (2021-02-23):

Ajustement du connecteur extrusion pour le dessus des extrusions

raphclou, 2021-02-23:
Le connecteur ne fit pas avec les trous. Il faut faire une autre version (ajouter une configuration) pour que ça fit avec les trous sur le dessus des extrusions

Closed 2021-03-04.

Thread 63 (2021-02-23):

Modification de railY

raphclou, 2021-02-23:
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[Uploading... PXL_20210223_164359088.MP.jpg]pour permettre la fixation de la plaque de connecteur

pour permettre de passer la courroie librement

Closed 2021-03-02.

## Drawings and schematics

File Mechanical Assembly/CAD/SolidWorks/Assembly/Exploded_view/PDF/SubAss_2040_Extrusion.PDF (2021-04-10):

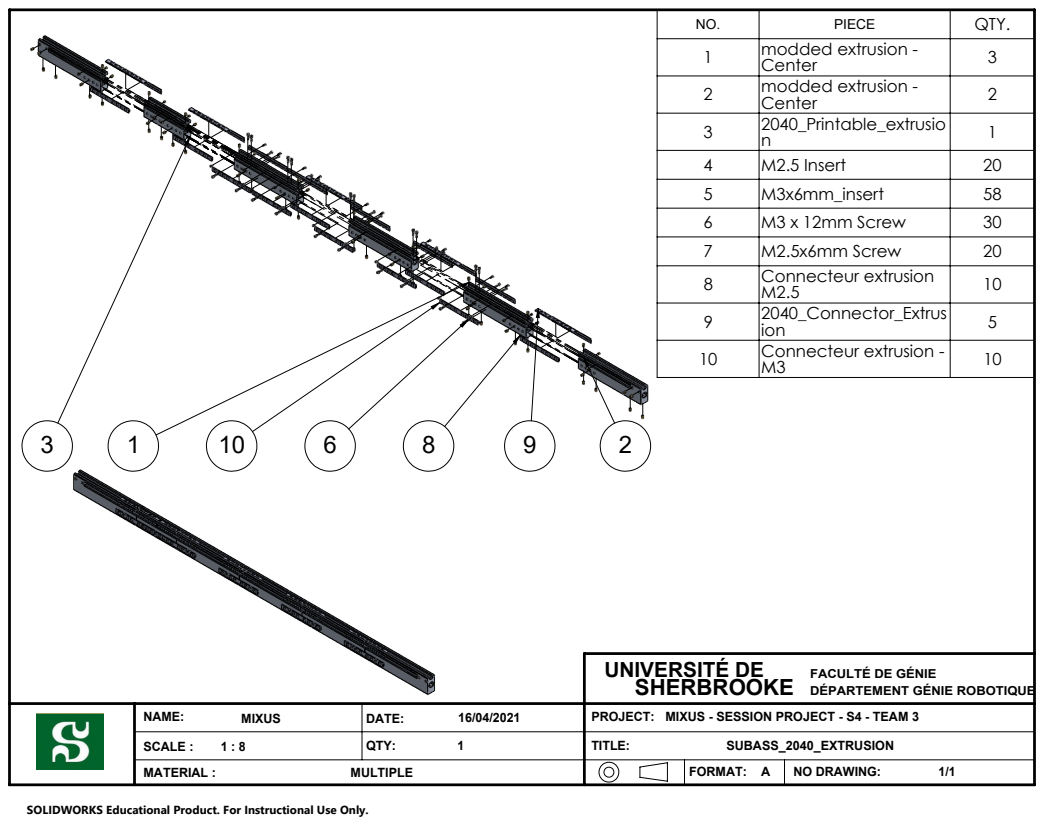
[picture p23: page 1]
FORMAT:; NO DRAWING:; SCALE :; MATERIAL :; UNIVERSITÉ DE

NO. | PIECE | QTY.
1 | modded extrusion -Center | 3
2 | modded extrusion -Center | 2
3 | 2040_Printable_extrusio n | 1
4 | M2.5 Insert | 20
5 | M3x6mm_insert | 58
6 | M3 x 12mm Screw | 30
7 | M2.5x6mm Screw | 20
8 | Connecteur extrusion M2.5 | 10
9 | 2040_Connector_Extrus ion | 5
10 | Connecteur extrusion -M3 | 10

FACULTÉ DE GÉNIE
DÉPARTEMENT GÉNIE ROBOTIQUE

MIXUS - SESSION PROJECT - S4 - TEAM 3

SOLIDWORKS Educational Product. For Instructional Use Only.

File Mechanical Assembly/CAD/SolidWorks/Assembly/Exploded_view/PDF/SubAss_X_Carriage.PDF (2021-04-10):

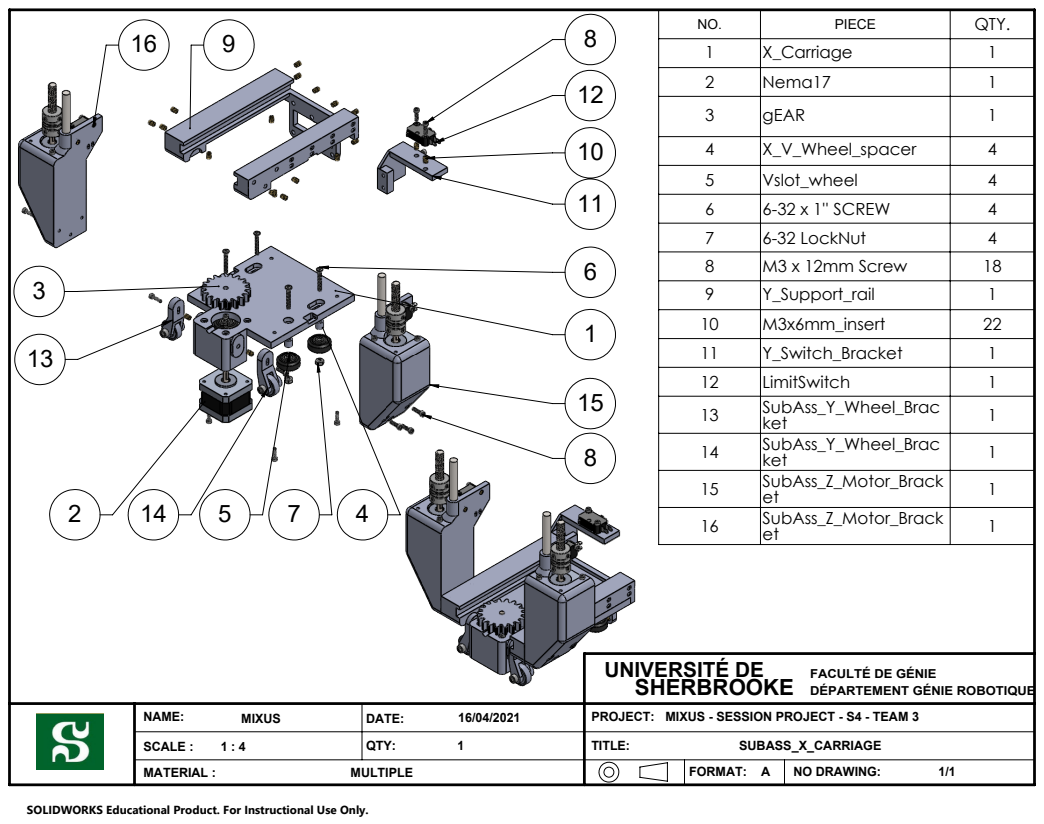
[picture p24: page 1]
FORMAT:; NO DRAWING:; SCALE :; MATERIAL :; UNIVERSITÉ DE

NO. | PIECE | QTY.
1 | X_Carriage | 1
2 | Nema17 | 1
3 | gEAR | 1
4 | X_V_Wheel_spacer | 4
5 | Vslot_wheel | 4
6 | 6-32 x 1'' SCREW | 4
7 | 6-32 LockNut | 4
8 | M3 x 12mm Screw | 18
9 | Y_Support_rail | 1
10 | M3x6mm_insert | 22
11 | Y_Switch_Bracket | 1
12 | LimitSwitch | 1
13 | SubAss_Y_Wheel_Brac ket | 1
14 | SubAss_Y_Wheel_Brac ket | 1
15 | SubAss_Z_Motor_Brack et | 1
16 | SubAss_Z_Motor_Brack et | 1

FACULTÉ DE GÉNIE
DÉPARTEMENT GÉNIE ROBOTIQUE

MIXUS - SESSION PROJECT - S4 - TEAM 3

SOLIDWORKS Educational Product. For Instructional Use Only.

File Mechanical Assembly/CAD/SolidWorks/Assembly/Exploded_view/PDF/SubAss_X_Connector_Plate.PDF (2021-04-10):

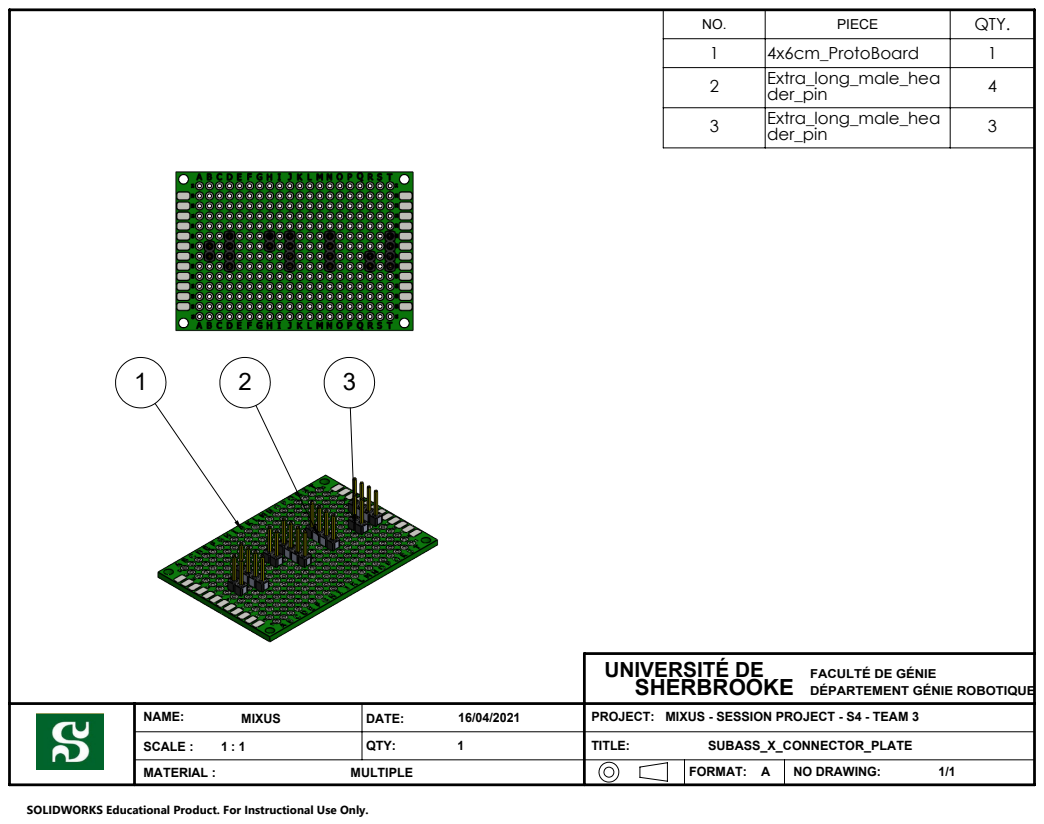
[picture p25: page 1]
FORMAT:; NO DRAWING:; SCALE :; MATERIAL :; UNIVERSITÉ DE

NO. | PIECE | QTY.
1 | 4x6cm_ProtoBoard | 1
2 | Extra_long_male_hea der_pin | 4
3 | Extra_long_male_hea der_pin | 3

FACULTÉ DE GÉNIE
DÉPARTEMENT GÉNIE ROBOTIQUE

MIXUS - SESSION PROJECT - S4 - TEAM 3
SUBASS_X_CONNECTOR_PLATE

SOLIDWORKS Educational Product. For Instructional Use Only.

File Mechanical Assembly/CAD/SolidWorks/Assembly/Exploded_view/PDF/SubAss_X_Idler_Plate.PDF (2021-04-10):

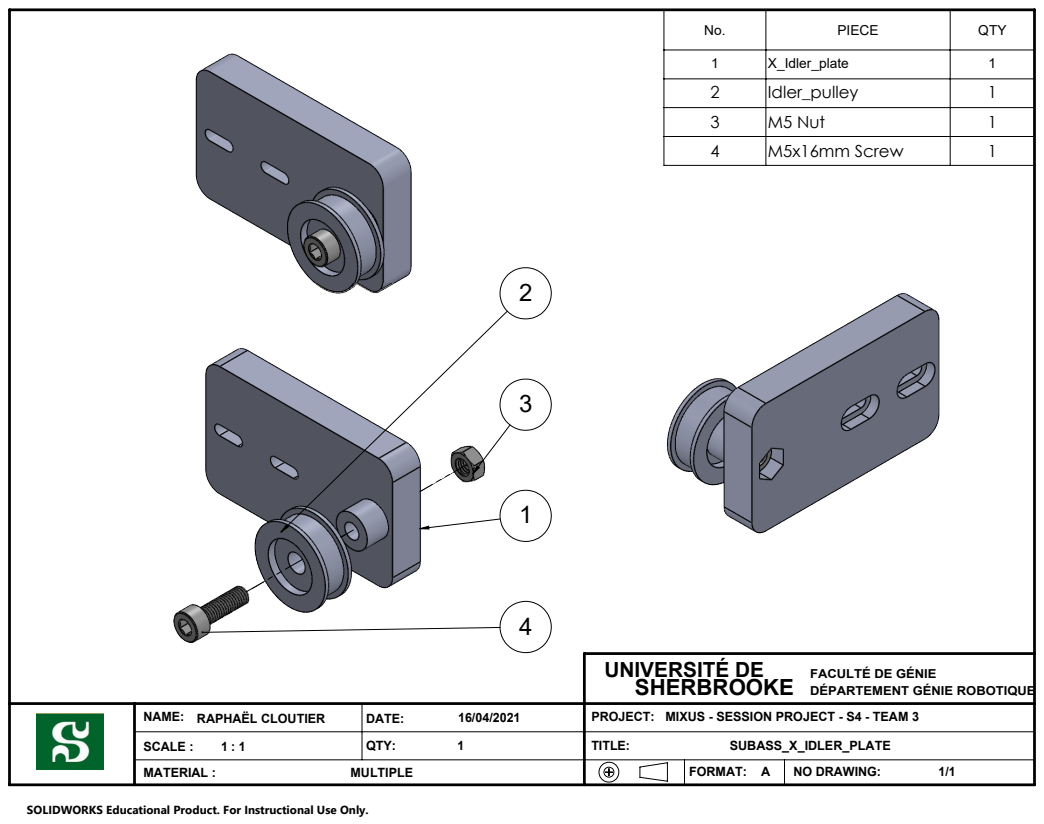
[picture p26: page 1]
FORMAT:; NO DRAWING:; SCALE :; MATERIAL :; RAPHAËL CLOUTIER; UNIVERSITÉ DE

No. | PIECE | QTY
1 | X_Idler_plate | 1
2 | Idler_pulley | 1
3 | M5 Nut | 1
4 | M5x16mm Screw | 1

FACULTÉ DE GÉNIE
DÉPARTEMENT GÉNIE ROBOTIQUE

MIXUS - SESSION PROJECT - S4 - TEAM 3

SOLIDWORKS Educational Product. For Instructional Use Only.

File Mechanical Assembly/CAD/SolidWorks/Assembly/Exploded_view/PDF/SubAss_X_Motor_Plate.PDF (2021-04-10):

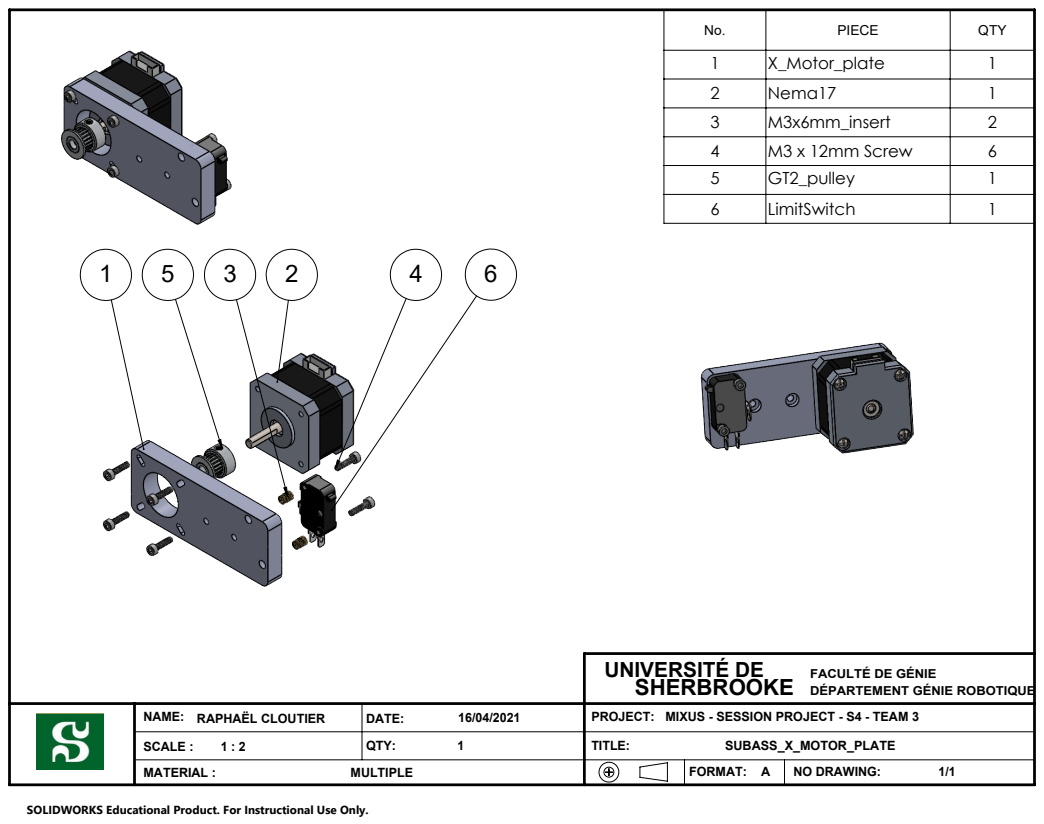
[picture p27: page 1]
FORMAT:; NO DRAWING:; SCALE :; MATERIAL :; RAPHAËL CLOUTIER; UNIVERSITÉ DE

No. | PIECE | QTY
1 | X_Motor_plate | 1
2 | Nema17 | 1
3 | M3x6mm_insert | 2
4 | M3 x 12mm Screw | 6
5 | GT2_pulley | 1
6 | LimitSwitch | 1

FACULTÉ DE GÉNIE
DÉPARTEMENT GÉNIE ROBOTIQUE

MIXUS - SESSION PROJECT - S4 - TEAM 3

SOLIDWORKS Educational Product. For Instructional Use Only.

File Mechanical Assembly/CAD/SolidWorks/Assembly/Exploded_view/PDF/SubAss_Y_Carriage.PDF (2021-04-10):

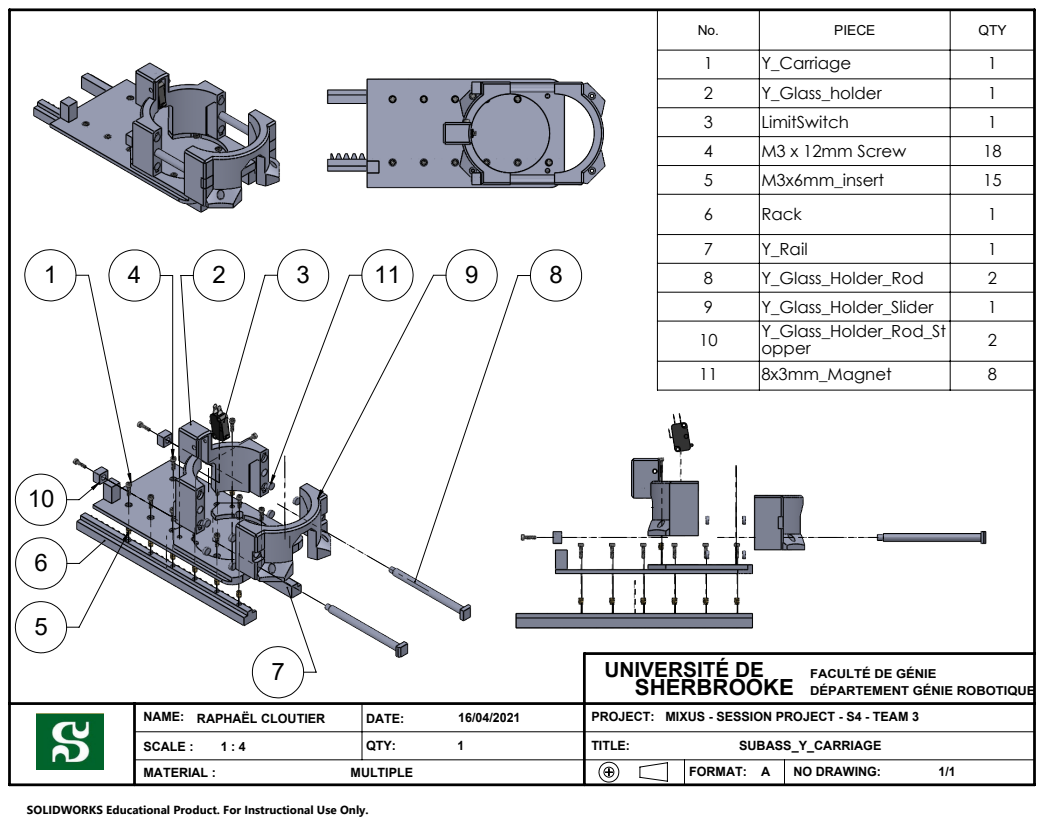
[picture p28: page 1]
FORMAT:; NO DRAWING:; SCALE :; MATERIAL :; RAPHAËL CLOUTIER; UNIVERSITÉ DE

No. | PIECE | QTY
1 | Y_Carriage | 1
2 | Y_Glass_holder | 1
3 | LimitSwitch | 1
4 | M3 x 12mm Screw | 18
5 | M3x6mm_insert | 15
6 | Rack | 1
7 | Y_Rail | 1
8 | Y_Glass_Holder_Rod | 2
9 | Y_Glass_Holder_Slider | 1
10 | Y_Glass_Holder_Rod_St opper | 2
11 | 8x3mm_Magnet | 8

FACULTÉ DE GÉNIE
DÉPARTEMENT GÉNIE ROBOTIQUE

MIXUS - SESSION PROJECT - S4 - TEAM 3

SOLIDWORKS Educational Product. For Instructional Use Only.

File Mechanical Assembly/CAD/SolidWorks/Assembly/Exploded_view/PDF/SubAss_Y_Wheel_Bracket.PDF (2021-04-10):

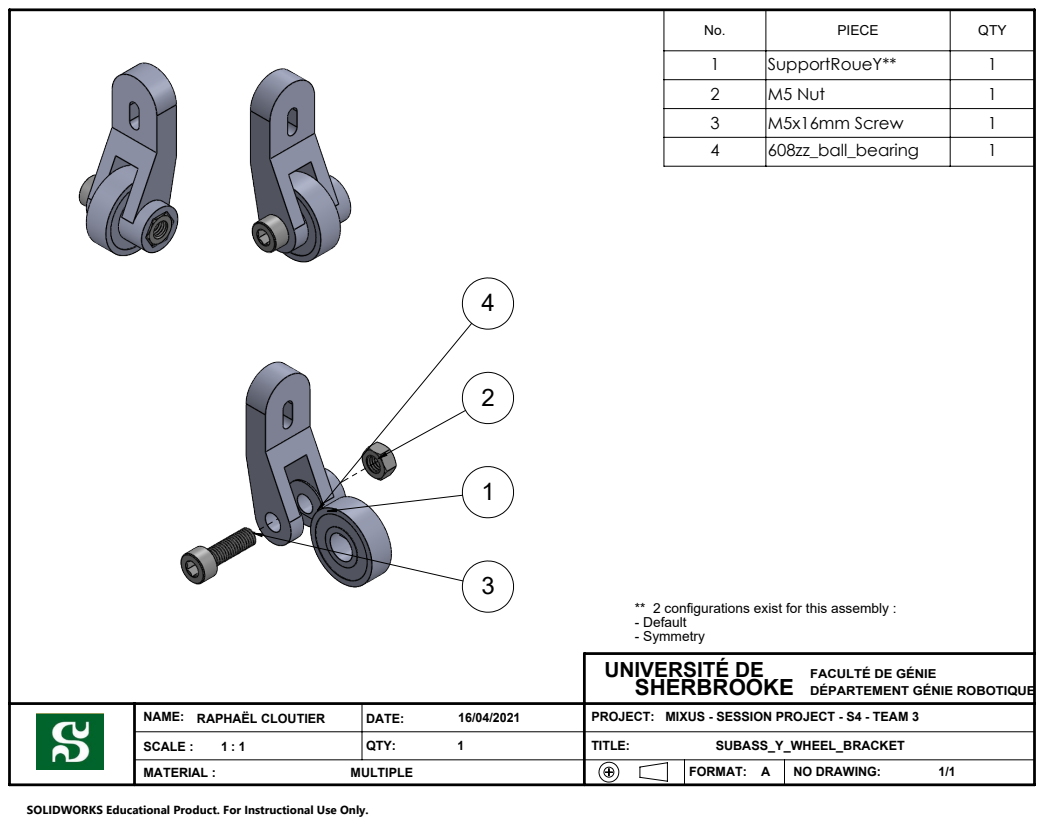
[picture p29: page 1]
FORMAT:; NO DRAWING:; SCALE :; MATERIAL :; RAPHAËL CLOUTIER

No. | PIECE | QTY
1 | SupportRoueY** | 1
2 | M5 Nut | 1
3 | M5x16mm Screw | 1
4 | 608zz_ball_bearing | 1

** 2 configurations exist for this assembly :
- Default
- Symmetry
UNIVERSITÉ DE
SHERBROOKE

FACULTÉ DE GÉNIE
DÉPARTEMENT GÉNIE ROBOTIQUE

MIXUS - SESSION PROJECT - S4 - TEAM 3
SUBASS_Y_WHEEL_BRACKET

SOLIDWORKS Educational Product. For Instructional Use Only.

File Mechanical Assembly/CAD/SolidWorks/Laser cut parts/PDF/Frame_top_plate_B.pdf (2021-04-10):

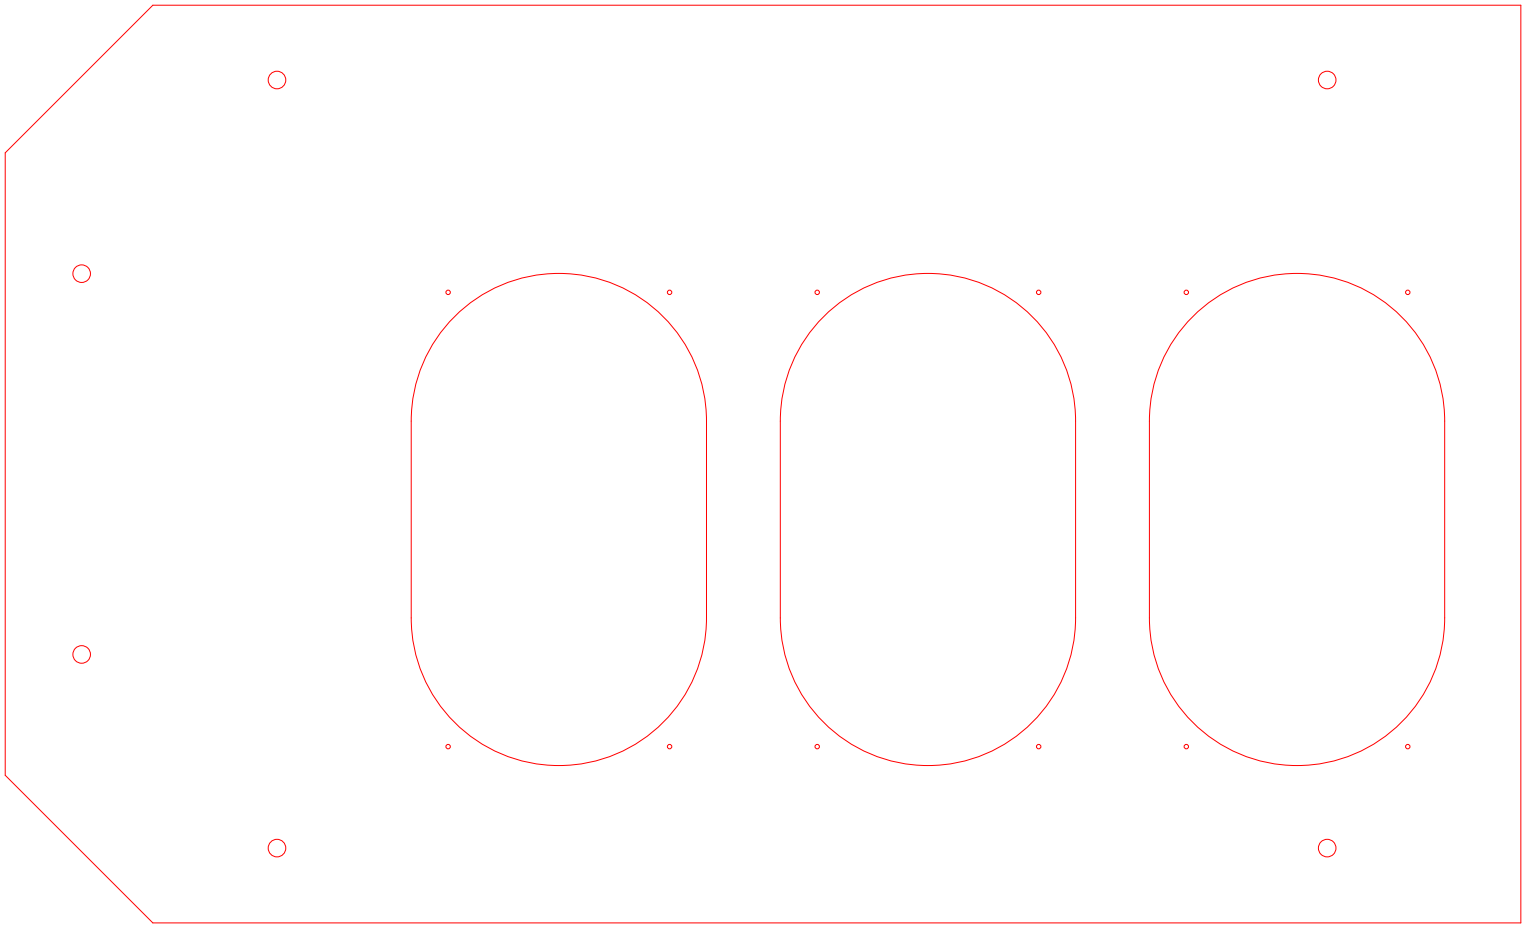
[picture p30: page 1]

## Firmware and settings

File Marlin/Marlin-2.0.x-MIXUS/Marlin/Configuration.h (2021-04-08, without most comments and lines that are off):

#pragma once
#define CONFIGURATION_H_VERSION 020007
#define STRING_CONFIG_H_AUTHOR "Raphaël Cloutier - Project MixUs Team #3 - Université de Sherbrooke - 2021" // Who made the changes.
#define SHOW_BOOTSCREEN
#define SERIAL_PORT 0
#define BAUDRATE 250000
#define MOTHERBOARD BOARD_RAMBO
#define EXTRUDERS 0
#define DEFAULT_NOMINAL_FILAMENT_DIA 1.75
#define TEMP_SENSOR_0 0
#define TEMP_SENSOR_1 0
#define TEMP_SENSOR_2 0
#define TEMP_SENSOR_3 0
#define TEMP_SENSOR_4 0
#define TEMP_SENSOR_5 0
#define TEMP_SENSOR_6 0
#define TEMP_SENSOR_7 0
#define TEMP_SENSOR_BED 0
#define TEMP_SENSOR_PROBE 0
#define TEMP_SENSOR_CHAMBER 0
#define DUMMY_THERMISTOR_998_VALUE 25
#define DUMMY_THERMISTOR_999_VALUE 100
#define MAX_REDUNDANT_TEMP_SENSOR_DIFF 10
#define TEMP_RESIDENCY_TIME 10 // (seconds) Time to wait for hotend to "settle" in M109
#define TEMP_WINDOW 1          // (°C) Temperature proximity for the "temperature reached" timer
#define TEMP_HYSTERESIS 3      // (°C) Temperature proximity considered "close enough" to the target
#define TEMP_BED_RESIDENCY_TIME 10 // (seconds) Time to wait for bed to "settle" in M190
#define TEMP_BED_WINDOW 1          // (°C) Temperature proximity for the "temperature reached" timer
#define TEMP_BED_HYSTERESIS 3      // (°C) Temperature proximity considered "close enough" to the target
#define HEATER_0_MINTEMP 5
#define HEATER_1_MINTEMP 5
#define HEATER_2_MINTEMP 5
#define HEATER_3_MINTEMP 5
#define HEATER_4_MINTEMP 5
#define HEATER_5_MINTEMP 5
#define HEATER_6_MINTEMP 5
#define HEATER_7_MINTEMP 5
#define BED_MINTEMP 5
#define HEATER_0_MAXTEMP 275
#define HEATER_1_MAXTEMP 275
#define HEATER_2_MAXTEMP 275
#define HEATER_3_MAXTEMP 275
#define HEATER_4_MAXTEMP 275
#define HEATER_5_MAXTEMP 275
#define HEATER_6_MAXTEMP 275
#define HEATER_7_MAXTEMP 275
#define BED_MAXTEMP 150
#define PIDTEMP
#define BANG_MAX 255     // Limits current to nozzle while in bang-bang mode; 255=full current
#define PID_MAX BANG_MAX // Limits current to nozzle while PID is active (see PID_FUNCTIONAL_RANGE below); 255=full current
#define PID_K1 0.95      // Smoothing factor within any PID loop
#define DEFAULT_Kp 22.20
#define DEFAULT_Ki 1.08
#define DEFAULT_Kd 114.00
#define MAX_BED_POWER 255 // limits duty cycle to bed; 255=full current
#define PID_FUNCTIONAL_RANGE 10 // If the temperature difference between the target temperature and the actual temperature \
#define PREVENT_COLD_EXTRUSION
#define EXTRUDE_MINTEMP 170
#define PREVENT_LENGTHY_EXTRUDE
#define EXTRUDE_MAXLENGTH 200
#define THERMAL_PROTECTION_HOTENDS // Enable thermal protection for all extruders
#define THERMAL_PROTECTION_BED     // Enable thermal protection for the heated bed
#define THERMAL_PROTECTION_CHAMBER // Enable thermal protection for the heated chamber
#define USE_XMIN_PLUG
#define USE_YMIN_PLUG
#define USE_ZMIN_PLUG
#define USE_ZMAX_PLUG
#define ENDSTOPPULLUPS
#define X_MIN_ENDSTOP_INVERTING false       // Set to true to invert the logic of the endstop.
#define Y_MIN_ENDSTOP_INVERTING false       // Set to true to invert the logic of the endstop.
#define Z_MIN_ENDSTOP_INVERTING false       // Set to true to invert the logic of the endstop.
#define X_MAX_ENDSTOP_INVERTING false       // Set to true to invert the logic of the endstop.
#define Y_MAX_ENDSTOP_INVERTING false       // Set to true to invert the logic of the endstop.
#define Z_MAX_ENDSTOP_INVERTING false       // Set to true to invert the logic of the endstop.
#define Z_MIN_PROBE_ENDSTOP_INVERTING false // Set to true to invert the logic of the probe.
#define X_DRIVER_TYPE A4988
#define Y_DRIVER_TYPE A4988
#define Z_DRIVER_TYPE A4988
#define Z2_DRIVER_TYPE A4988
#define DEFAULT_AXIS_STEPS_PER_UNIT \
  {                                 \
    80, 20.220658, 400, 400         \
  }
#define DEFAULT_MAX_FEEDRATE \
  {                          \
    600, 300, 25, 25         \
  }
#define DEFAULT_MAX_ACCELERATION \
  {                              \
    1000, 1000, 100, 10000       \
  }
#define DEFAULT_ACCELERATION 3000         // X, Y, Z and E acceleration for printing moves
#define DEFAULT_RETRACT_ACCELERATION 3000 // E acceleration for retracts
#define DEFAULT_TRAVEL_ACCELERATION 3000  // X, Y, Z acceleration for travel (non printing) moves
#define DEFAULT_EJERK 5.0 // May be used by Linear Advance
#define JUNCTION_DEVIATION_MM 0.013 // (mm) Distance from real junction edge
#define JD_HANDLE_SMALL_SEGMENTS    // Use curvature estimation instead of just the junction angle \
#define NOZZLE_TO_PROBE_OFFSET \
  {                            \
    10, 10, 0                  \
  }
#define PROBING_MARGIN 10
#define XY_PROBE_SPEED (133 * 60)
#define Z_PROBE_SPEED_FAST HOMING_FEEDRATE_Z
#define Z_PROBE_SPEED_SLOW (Z_PROBE_SPEED_FAST / 2)
#define Z_CLEARANCE_DEPLOY_PROBE 10  // Z Clearance for Deploy/Stow
#define Z_CLEARANCE_BETWEEN_PROBES 5 // Z Clearance between probe points
#define Z_CLEARANCE_MULTI_PROBE 5    // Z Clearance between multiple probes
#define Z_PROBE_LOW_POINT -2 // Farthest distance below the trigger-point to go before stopping
#define Z_PROBE_OFFSET_RANGE_MIN -20
#define Z_PROBE_OFFSET_RANGE_MAX 20
#define X_ENABLE_ON 0
#define Y_ENABLE_ON 0
#define Z_ENABLE_ON 0
#define E_ENABLE_ON 0 // For all extruders
#define DISABLE_X false
#define DISABLE_Y false
#define DISABLE_Z false
#define DISABLE_E false           // Disable the extruder when not stepping
#define DISABLE_INACTIVE_EXTRUDER // Keep only the active extruder enabled
#define INVERT_X_DIR false
#define INVERT_Y_DIR true
#define INVERT_Z_DIR false
#define INVERT_E0_DIR false
#define INVERT_E1_DIR false
#define INVERT_E2_DIR false
#define INVERT_E3_DIR false
#define INVERT_E4_DIR false
#define INVERT_E5_DIR false
#define INVERT_E6_DIR false
#define INVERT_E7_DIR false
#define Z_HOMING_HEIGHT 0.5 // (mm) Minimal Z height before homing (G28) for Z clearance above the bed, clamps, ...
#define X_HOME_DIR -1
#define Y_HOME_DIR -1
#define Z_HOME_DIR -1
#define X_BED_SIZE 810
#define Y_BED_SIZE 150
#define X_MIN_POS 0
#define Y_MIN_POS 0
#define Z_MIN_POS 0
#define X_MAX_POS X_BED_SIZE
#define Y_MAX_POS Y_BED_SIZE
#define Z_MAX_POS 20
#define MIN_SOFTWARE_ENDSTOPS
#define MIN_SOFTWARE_ENDSTOP_X
#define MIN_SOFTWARE_ENDSTOP_Y
#define MIN_SOFTWARE_ENDSTOP_Z
#define MAX_SOFTWARE_ENDSTOPS
#define MAX_SOFTWARE_ENDSTOP_X
#define MAX_SOFTWARE_ENDSTOP_Y
#define MAX_SOFTWARE_ENDSTOP_Z
#define HOMING_FEEDRATE_XY (50 * 60)
#define HOMING_FEEDRATE_Z (500)
#define VALIDATE_HOMING_ENDSTOPS
#define EEPROM_CHITCHAT    // Give feedback on EEPROM commands. Disable to save PROGMEM.
#define EEPROM_BOOT_SILENT // Keep M503 quiet and only give errors during first load
#define HOST_KEEPALIVE_FEATURE       // Disable this if your host doesn't like keepalive messages
#define DEFAULT_KEEPALIVE_INTERVAL 2 // Number of seconds between "busy" messages. Set with M113.
#define BUSY_WHILE_HEATING           // Some hosts require "busy" messages even during heating
#define PREHEAT_1_LABEL "PLA"
#define PREHEAT_1_TEMP_HOTEND 180
#define PREHEAT_1_TEMP_BED 70
#define PREHEAT_1_FAN_SPEED 0 // Value from 0 to 255
#define PREHEAT_2_LABEL "ABS"
#define PREHEAT_2_TEMP_HOTEND 240
#define PREHEAT_2_TEMP_BED 110
#define PREHEAT_2_FAN_SPEED 0 // Value from 0 to 255
#define PRINTJOB_TIMER_AUTOSTART
#define LCD_LANGUAGE en
#define DISPLAY_CHARSET_HD44780 JAPANESE
#define LCD_INFO_SCREEN_STYLE 0
#define SOFT_PWM_SCALE 0
#define SERVO_DELAY \
  {                 \
    300             \
  }

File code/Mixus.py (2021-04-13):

from PyQt5 import QtWidgets, uic, QtGui
from PyQt5.QtGui import QFont, QIcon
from PyQt5.QtCore import Qt, pyqtSignal, pyqtSlot
from PyQt5.QtWidgets import QComboBox, QLabel, QMainWindow, QDialog, QStackedWidget, QPushButton, \
    QHBoxLayout, QLayout, QWidget
from DataModel import *
from JsonHandler import JsonHandler
from Enums import *
from UIManager import *
from LimitSwitch import LimitSwitch
from SerialCommunication import SerialSynchroniser
from Popup import Popup
import sys


class BottleLayout(QHBoxLayout):
    """
    Layout to allow modification of liquid type and volume of bottles on the machine
    ComboBoxes are used to get user input
    """
    slot_number = None
    liquid_type_combo_box = None
    volume_left_combo_box = None

    def __init__(self, temp_bottle, ui_manager):
        super().__init__()
        self.bottle = temp_bottle
        self.ui_manager = ui_manager

        self.ui_manager.bottle_layout_setup(self)

    def add_widget_to_superclass(self, widget):
        super().addWidget(widget)

    def init_combo_box(self, combo_box, selected_item, items):
        # First item added is selected
        combo_box.addItem(selected_item)

        for item in items:
            if item != selected_item:
                combo_box.addItem(item)

    def new_liquid_type_selected(self):
        self.bottle.set_liquid(Liquid.get_liquid_from_string_name(self.liquid_type_combo_box.currentText()))

    def new_volume_selected(self):
        self.bottle.set_volume_left(int(self.volume_left_combo_box.currentText()))

    def update_layout(self, new_bottle):
        """
        Update the layout to display status of new_bottle
        :param new_bottle: bottle used to update combo boxes
        :return:
        """
        self.bottle = new_bottle
        self.liquid_type_combo_box.clear()
        self.volume_left_combo_box.clear()

        self.init_combo_box(self.liquid_type_combo_box, self.bottle.get_liquid_name(), Liquid.list())
        self.init_combo_box(self.volume_left_combo_box, str(self.bottle.get_volume_left()), BottleSize.list())


class BottleMenu(QDialog):
    """
    Menu to update the software when bottles are changed on the machine
    """
    name = "BottleMenu"
    bottle_manager = []
    temp_bottles = []
    bottle_layouts = {}
    window_manager = None

    def __init__(self, window_manager, ui_manager, bottle_manager):
        super(BottleMenu, self).__init__()
        uic.loadUi(Paths.BOTTLE_MENU.value, self)
        self.window_manager = window_manager
        self.bottle_manager = bottle_manager
        self.ui_manager = ui_manager
        self.ui_manager.bottle_menu_setup(self)
        self.connect_buttons()
        self.bottles_setup()

    def bottles_setup(self):
        for bottle in self.bottle_manager.get_bottles():
            temp_bottle = bottle.copy()
            self.temp_bottles.append(temp_bottle)
            bottle_layout = BottleLayout(temp_bottle, self.ui_manager)
            self.bottle_layouts.update({temp_bottle.get_slot_number(): bottle_layout})
            self.scroll_layout.addLayout(bottle_layout)

    def connect_buttons(self):
        self.pushButton_return.released.connect(lambda: self.window_manager.switch_window("MaintenanceMenu"))
        self.pushButton_confirm.released.connect(self.confirm_button_released)

    def confirm_button_released(self):
        # save changes done in the menu to the bottle list accessible by other menus
        self.bottle_manager.update(self.temp_bottles)
        self.window_manager.switch_window("MainMenu")

    def update_layout(self):

        """
        Method called when the bottle menu is loaded
        Updates each bottle layout with the current content of bottle manager
        :return:
        """
        self.temp_bottles.clear()
        for bottle in self.bottle_manager.get_bottles():
            temp_bottle = bottle.copy()
            self.temp_bottles.append(temp_bottle)
            self.bottle_layouts.get(temp_bottle.get_slot_number()).update_layout(temp_bottle)


class MixingMenu(QDialog):
    name = "MixingMenu"
    progress = pyqtSignal(int)
    checkpoint_reached = pyqtSignal(str)
    instruction_completed = pyqtSignal()
    drink_completed = pyqtSignal()

    def __init__(self, window_manager, ui_manager, bottle_manager):
        super(MixingMenu, self).__init__()
        uic.loadUi(Paths.MIXING_MENU.value, self)
        self.ui_manager = ui_manager
        self.window_manager = window_manager
        self.bottle_manager = bottle_manager
        self.connect_buttons()
        self.ui_manager.mixing_menu_setup(self)
        self.serial_synchroniser = SerialSynchroniser()
        self.drink = None
        self.cup_switch = LimitSwitch()

    def connect_buttons(self):
        self.pushButton_return.released.connect(self.return_button_action)
        self.progress.connect(self.update_progress_bar)
        self.checkpoint_reached.connect(self.update_ingredients)
        self.drink_completed.connect(self.popup)

    def update_layout(self, instructions, checkpoints, drink):
        """
        Method called when the MixingMenu is loaded
        Updates the ingredients and the progressBar for the current drink
        :param instructions: List of instructions to pass to the serial port
        :param checkpoints: Checkpoints of the instruction list to update ingredients 
        :param drink: Drink that is going to be made
        :return: 
        """""
        self.ui_manager.image_setup(self.label_drinkImage, drink.image_path)
        self.label_Title.setText(drink.name)
        self.drink = drink
        self.progressBar.setValue(0)
        self.ingredient_labels = {}

        for i in range(0, self.verticalLayout_waiting.count()):
            self.verticalLayout_waiting.itemAt(i).widget().deleteLater()
        for i in range(0, self.verticalLayout_done.count()):
            self.verticalLayout_done.itemAt(i).widget().deleteLater()

        for ingredient in drink.liquids:
            label = QLabel()
            label.setText(ingredient.string_name)
            label.setFont(QFont("Times", 12))
            self.ingredient_labels.update({ingredient.string_name: label})
            self.verticalLayout_waiting.addWidget(label)

        if self.serial_synchroniser.can_start_communication():
            self.start_mixing(instructions, checkpoints)
        else:
            connect_and_retry(lambda: self.start_mixing(instructions, checkpoints))

    def start_mixing(self, instructions, checkpoints):
        self.serial_synchroniser.track_progress(self, checkpoints, len(instructions))
        self.serial_synchroniser.begin_communication(instructions)

    def return_button_action(self):
        self.serial_synchroniser.abort_communication()
        if self.serial_synchroniser.can_start_communication():
            self.end_mixing(drink_canceled=True)
        else:
            connect_and_retry(lambda: self.end_mixing(drink_canceled=True))

    def end_mixing(self, drink_canceled=False):
        self.serial_synchroniser.begin_communication(GCodeGenerator.serve_cup())
        self.popup(drink_canceled)

    def update_progress_bar(self, value):
        self.progressBar.setValue(value)

    def update_ingredients(self, liquid_name):
        label = self.ingredient_labels.get(liquid_name)
        self.verticalLayout_waiting.removeWidget(label)
        self.verticalLayout_done.addWidget(label)
        self.bottle_manager.pour(liquid_name, self.drink.ingredients.get(liquid_name))

    def popup(self, drink_canceled=False):
        Popup.drink_completed(self.load_main_menu, drink_canceled=drink_canceled)

    def load_main_menu(self):
        if not self.cup_switch.is_activated(expected=False):
            if self.serial_synchroniser.can_start_communication():
                self.serial_synchroniser.track_progress(self.window_manager.get_window("MainMenu"))
                self.serial_synchroniser.begin_communication(GCodeGenerator.insert_cup())
                self.window_manager.switch_window("MainMenu", in_motion=True)
            else:
                connect_and_retry(self.popup())
        else:
            Popup.drink_completed(self.load_main_menu)


class DrinkOptionMenu(QDialog):
    name = "DrinkOptionMenu"
    progress = pyqtSignal(int)
    checkpoint_reached = pyqtSignal(str)
    instruction_completed = pyqtSignal()
    in_motion = False
    drink = None

    def __init__(self, window_manager, ui_manager, drink_manager):
        super(DrinkOptionMenu, self).__init__()
        uic.loadUi(Paths.DRINK_OPTION_MENU.value, self)
        self.window_manager = window_manager
        self.drink_manager = drink_manager
        self.ui_manager = ui_manager
        self.serial_synchroniser = SerialSynchroniser()
        self.cup_switch = LimitSwitch()

        ui_manager.drink_option_menu_setup(self)

        self.radioButton_normal.toggled.connect(self.update_ingredients)
        self.radioButton_double.toggled.connect(self.update_ingredients)
        self.radioButton_virgin.toggled.connect(self.update_ingredients)

        self.pushButton_return.released.connect(self.return_button_action)
        self.pushButton_confirm.released.connect(self.load_mixing_menu)
        self.instruction_completed.connect(self.__on_instruction_completed)

    def update_layout(self, drink):
        self.drink = drink
        self.label_Title.setText(self.drink.name.replace("_", " "))
        self.radioButton_normal.setChecked(True)
        self.ui_manager.image_setup(self.label_drinkImage, self.drink.image_path)
        self.request_cup()
        self.update_ingredients()

    def return_button_action(self):
        if self.serial_synchroniser.can_start_communication():
            self.load_main_menu()
        else:
            connect_and_retry(self.load_main_menu)

    def request_cup(self):
        if self.serial_synchroniser.can_start_communication():
            self.__send_command(GCodeGenerator.wait_for_cup())
        else:
            connect_and_retry(lambda: self.__send_command(GCodeGenerator.wait_for_cup()))

    def __send_command(self, instructions):
        self.pushButton_return.setEnabled(False)
        self.pushButton_confirm.setEnabled(False)
        self.in_motion = True
        self.serial_synchroniser.track_progress(self)
        self.serial_synchroniser.begin_communication(instructions)

    def __on_instruction_completed(self):
        self.pushButton_return.setEnabled(True)
        self.pushButton_confirm.setEnabled(True)
        self.in_motion = False
        self.update_ingredients()

    def update_ingredients(self):
        self.is_current_setting_valid()

        for i in range(0, self.verticalLayout_ingredients.count()):
            self.verticalLayout_ingredients.itemAt(i).widget().deleteLater()

        flag = 0
        for liquid in list(self.drink.liquids):
            l = LiquidLabel(liquid, self.drink.ingredients.get(liquid.string_name))
            vol = self.drink.ingredients.get(l.liquid.string_name)
            if self.radioButton_normal.isChecked():
                l.update_volume(vol)
            elif self.radioButton_double.isChecked():
                if l.liquid.is_alcoholized:
                    l.update_volume(vol * 2)
                elif l.liquid.is_filler:
                    volume_to_remove = self.drink.alcohol_volume()
                    l.update_volume(
                        vol - volume_to_remove)
                else:
                    l.update_volume(vol)
            elif self.radioButton_virgin.isChecked():
                if l.liquid.is_alcoholized:
                    flag = 1
                elif l.liquid.is_filler:
                    volume_to_add = self.drink.alcohol_volume()
                    l.update_volume(vol + volume_to_add)
                else:
                    l.update_volume(vol)

            if flag == 0:
                self.verticalLayout_ingredients.addWidget(l)
            else:
                flag = 0

    # Disable confirm button if the drink cant be made with current settings
    def is_current_setting_valid(self):
        is_valid = not self.in_motion and \
                   ((self.radioButton_double.isChecked() and self.is_double_available()) or
                    (self.radioButton_virgin.isChecked() and self.is_virgin_available()) or
                    self.radioButton_normal.isChecked())
        self.pushButton_confirm.setEnabled(is_valid)

    def is_double_available(self):
        return self.drink_manager.is_double_available(self.drink)

    def is_virgin_available(self):
        return self.drink_manager.is_virgin_available(self.drink)

    def load_mixing_menu(self):
        if self.cup_switch.is_activated():
            instructions, liquid_checkpoints = self.drink_manager.get_instructions(self.drink,
                                                                                   self.radioButton_double.isChecked(),
                                                                                   self.radioButton_virgin.isChecked())

            self.window_manager.switch_window("MixingMenu",
                                              drink=self.drink,
                                              instructions=instructions,
                                              checkpoints=liquid_checkpoints)
        else:
            Popup.no_cup_error(self.load_mixing_menu)

    def load_main_menu(self):
        self.serial_synchroniser.track_progress(self.window_manager.get_window("MainMenu"))
        self.serial_synchroniser.begin_communication(GCodeGenerator.insert_cup())
        self.window_manager.switch_window("MainMenu", in_motion=True)


class MaintenanceMenu(QDialog):
    name = "MaintenanceMenu"
    progress = pyqtSignal(int)
    checkpoint_reached = pyqtSignal(str)
    instruction_completed = pyqtSignal()
    is_home = True
    x_value = 0
    y_value = 0
    z_value = 0

    def __init__(self, window_manager, ui_manager):
        super(MaintenanceMenu, self).__init__()
        uic.loadUi(Paths.MAINTENANCE_MENU.value, self)
        self.window_manager = window_manager
        self.serial_synchroniser = SerialSynchroniser()
        self.instruction_completed.connect(self.on_instruction_completed)
        self.pushButton_return.clicked.connect(lambda: self.change_window("MainMenu"))
        self.pushButton_bottle.clicked.connect(lambda: self.change_window("BottleMenu"))
        self.pushButton_send.clicked.connect(self.send_button_action)
        self.pushButton_home.clicked.connect(self.home_button_action)
        self.pushButton_disable.clicked.connect(self.disable_button_action)
        self.slider.valueChanged.connect(self.label_axis_update)
        self.comboBox_axis.currentIndexChanged.connect(lambda: self.slider_update(self.comboBox_axis.currentText()))
        self.combobox_axis_setup()

        ui_manager.maintenance_menu_setup(self)

    def combobox_axis_setup(self):
        self.comboBox_axis.addItem('X')
        self.comboBox_axis.addItem('Y')
        self.comboBox_axis.addItem('Z')
        self.label_axis.setText('0')

    def slider_update(self, axis):
        if axis == 'X':
            temp_val = self.x_value
            self.slider.setMaximum(GCodeGenerator.max_x)
            self.x_value = temp_val
            self.slider.setValue(self.x_value)
            self.label_axis.setText(str(self.slider.value()))
        elif axis == 'Y':
            temp_val = self.y_value
            self.slider.setMaximum(GCodeGenerator.max_y)
            self.y_value = temp_val
            self.slider.setValue(self.y_value)
            self.label_axis.setText(str(self.slider.value()))
        elif axis == 'Z':
            temp_val = self.z_value
            self.slider.setMaximum(GCodeGenerator.max_z)
            self.z_value = temp_val
            self.slider.setValue(self.z_value)
            self.label_axis.setText(str(self.slider.value()))
        else:
            raise ValueError("Axis given was not X, Y or Z")

    def label_axis_update(self):
        self.label_axis.setText(str(self.slider.value()))
        if self.comboBox_axis.currentText() == 'X':
            self.x_value = self.slider.value()
        elif self.comboBox_axis.currentText() == 'Y':
            self.y_value = self.slider.value()
        elif self.comboBox_axis.currentText() == 'Z':
            self.z_value = self.slider.value()

    def send_button_action(self):
        self.is_home = False
        instructions = GCodeGenerator.move_axis(int(self.label_axis.text()), self.comboBox_axis.currentText())
        if self.serial_synchroniser.can_start_communication():
            self.__send_command(instructions)
        else:
            connect_and_retry(lambda: self.__send_command(instructions))

    def on_instruction_completed(self):
        self.pushButton_send.setEnabled(True)
        self.pushButton_home.setEnabled(True)
        self.pushButton_return.setEnabled(True)
        self.pushButton_bottle.setEnabled(True)
        self.pushButton_disable.setEnabled(True)

    def home_button_action(self):
        self.is_home = True
        instructions = GCodeGenerator.home()
        if self.serial_synchroniser.can_start_communication():
            self.__send_command(instructions)
        else:
            connect_and_retry(lambda: self.__send_command(instructions))
        self.x_value = 0
        self.y_value = 0
        self.z_value = 0
        self.slider_update(self.comboBox_axis.currentText())

    def disable_button_action(self):
        self.is_home = False
        instructions = GCodeGenerator.disable_steppers()
        if self.serial_synchroniser.can_start_communication():
            self.__send_command(instructions)
        else:
            connect_and_retry(lambda: self.__send_command(instructions))

    def change_window(self, window_name):
        if not self.is_home:
            Popup.home_before_leaving(self.home_button_action)
        else:
            self.window_manager.switch_window(window_name)

    def __send_command(self, instructions):
        self.pushButton_send.setEnabled(False)
        self.pushButton_home.setEnabled(False)
        self.pushButton_return.setEnabled(False)
        self.pushButton_bottle.setEnabled(False)
        self.pushButton_disable.setEnabled(False)
        self.serial_synchroniser.track_progress(self)
        self.serial_synchroniser.begin_communication(instructions)


class MainMenu(QMainWindow):
    name = "MainMenu"
    progress = pyqtSignal(int)
    checkpoint_reached = pyqtSignal(str)
    instruction_completed = pyqtSignal()

    def __init__(self, window_manager, ui_manager, drink_manager):
        super(MainMenu, self).__init__()
        uic.loadUi(Paths.MAIN_MENU.value, self)
        self.window_manager = window_manager
        self.drink_manager = drink_manager
        self.scroll_layout = QHBoxLayout(self.scrollAreaWidgetContents)

        self.connect_buttons()
        self.instruction_completed.connect(self.__on_instruction_completed)
        ui_manager.main_menu_setup(self)

        self.update_layout()

    def update_layout(self, in_motion=False):
        for i in reversed(range(self.scroll_layout.count())):
            self.scroll_layout.itemAt(i).widget().deleteLater()
        for drink in self.drink_manager.get_available_drinks():
            drink_button = DrinkButton(self.scrollAreaWidgetContents, drink)
            self.scroll_layout.addWidget(drink_button)
            drink_button.button.released.connect(
                lambda button_drink=drink_button.drink: self.window_manager.switch_window("DrinkOptionMenu",
                                                                                          drink=button_drink))
        if in_motion:
            self.enable_buttons(False)

    def connect_buttons(self):
        self.pushButton_maintenance.clicked.connect(lambda: self.window_manager.switch_window("MaintenanceMenu"))
        self.pushButton_exit.clicked.connect(lambda: sys.exit(app.exec_()))

    def enable_buttons(self, enable=True):
        self.pushButton_maintenance.setEnabled(enable)
        self.pushButton_exit.setEnabled(enable)

        drink_buttons = (self.scroll_layout.itemAt(i) for i in range(self.scroll_layout.count()))
        for drink_button in drink_buttons:
            drink_button.widget().setEnabled(enable)

    def __on_instruction_completed(self):
        self.enable_buttons()


class DrinkButton(QWidget):
    def __init__(self, scroll_area_widget_contents, drink):
        super(DrinkButton, self).__init__(scroll_area_widget_contents)
        self.drink = drink
        self.button = QPushButton()
        self.label = QLabel(drink.name.replace("_", " "))

        self.button.setStyleSheet("QPushButton{ background-image: url(" + self.drink.image_path + "); }")
        self.button.setFixedSize(Style.drink_button_image_size.value)

        self.label.setAlignment(Qt.AlignCenter)
        self.label.setFont(QFont("Times", 9, QFont.Bold))

        self.setFixedSize(Style.drink_button_size.value)

        self.layout = QVBoxLayout()
        self.layout.addWidget(self.button)
        self.layout.addWidget(self.label)
        self.setLayout(self.layout)


class LiquidLabel(QLabel):
    def __init__(self, liquid, volume):
        super(LiquidLabel, self).__init__()
        self.liquid = liquid
        self.volume = volume
        self.setText(str(volume) + " onces de " + str.lower(self.liquid.string_name))
        self.setFont(QFont("Times", 12))

    def update_volume(self, volume):
        self.volume = volume
        self.setText(str(volume) + " onces de " + str.lower(self.liquid.string_name))
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

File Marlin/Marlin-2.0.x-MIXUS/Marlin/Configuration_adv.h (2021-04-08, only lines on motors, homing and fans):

#define E0_AUTO_FAN_PIN -1
#define E1_AUTO_FAN_PIN -1
#define E2_AUTO_FAN_PIN -1
#define E3_AUTO_FAN_PIN -1
#define E4_AUTO_FAN_PIN -1
#define E5_AUTO_FAN_PIN -1
#define E6_AUTO_FAN_PIN -1
#define E7_AUTO_FAN_PIN -1
#define CHAMBER_AUTO_FAN_PIN -1
#define HOMING_BUMP_MM      { 5, 5, 2 }       // (mm) Backoff from endstops after first bump
#define HOMING_BUMP_DIVISOR { 2, 2, 4 }       // Re-Bump Speed Divisor (Divides the Homing Feedrate)
#define MICROSTEP_MODES { 16, 16, 16, 16, 16, 16 } // [1,2,4,8,16]
#define DIGIPOT_MOTOR_CURRENT { 135,150,160,160,135 }   // Values 0-255 (RAMBO 135 = ~0.75A, 185 = ~1A)

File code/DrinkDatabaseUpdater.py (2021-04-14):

from __future__ import print_function, unicode_literals

import sys, os

import inquirer as inquirer

from DataModel import *
from Enums import Paths, Liquid
from JsonHandler import JsonHandler

from PyInquirer import style_from_dict, Token, prompt
from pprint import pprint

max_volume = 8  # Max volume (in ounces) in a drink


class CmdUI:
    drink_name = None
    drink_liquids = []
    ingredient_dict = {}
    image_path = None

    def __init__(self, drink_manager):
        self.liquids = Liquid.list()[1:]
        self.drink_manager = drink_manager
        self.__style()

    def __style(self):
        self.style = style_from_dict({
            Token.Separator: '#cc5454',
            Token.QuestionMark: '#673ab7 bold',
            Token.Selected: '#cc5454',  # default
            Token.Pointer: '#673ab7 bold',
            Token.Instruction: '',  # default
            Token.Answer: '#f44336 bold',
            Token.Question: '',
        })

    @staticmethod
    def action_inquirer():
        action = prompt([
            {
                'type': 'list',
                'message': 'Sélectionner votre choix',
                'name': 'output',
                'choices': [
                    'Ajouter une nouvelle boisson à la base de données',
                    'Retirer une boisson de la base de données',
                ],
            }
        ])['output']

        print(action)
        return action.startswith('Ajouter')


    def drink_name_inquirer(self):
        self.drink_name = prompt([
            {
                'type': 'input',
                'message': '\nNom de la nouvelle Boisson \n (Pour annuler, entrer: exit):',
                'name': 'output',
                'validate': lambda answer: \
                    'Le nom de la boisson doit avoir au moins 4 charactères' if self.__verify_drink_name(answer) == 0 \
                        else (
                        'Une boisson portant ce nom existe déjà dans la base de données' if self.__verify_drink_name(
                            answer) == 1 else True),

            }
        ], style=self.style)["output"]
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

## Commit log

2021-02-07 scriptconfig
    ajout d'un .bat afin de configurer les libraries de python sur l'ordinateur de l'utilisateur.
2021-02-10 Added a builder for bottle layout
    Todo : add runnable to bind with edit buttons in bottle menu
2021-02-20 BottleLayout fix according to modifications in DataModel
    [Mixus.py]
2021-02-24 Added external box CAD
    [Panneau de dessus.STEP, cadre hauteur.STEP, cadre largeur.STEP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]
2021-02-24 Added Movement mecanism Cad, Marlin code, Technical drawings
    [Configuration.h, Configuration_adv.h, How to setup Marlin.xlsx]
2021-02-24 Added Bill of material
2021-03-03 Added unit testing and fixed encountered bugs
    [JsonHandler.py, PersistenceTest.py, SerialCommunication.py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]
2021-03-10 Fix import errors + modification according to com tests with rambo board
    [Enums.py, JsonHandler.py, Mixus.py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]
2021-03-10 More import errors fixed
    [JsonHandler.py]
2021-03-13 DrinkOptionMenu IngredientLayout fixed
    Added a new functionnality that shows the volume of the ingredients depending on if the drink is doubled, virgin or normal
    [Mixus.py]
2021-03-24 Implemented detection of limit switch with associated popup + port detection
2021-03-25 Fixed Felix Logic (again) + limit switch (Fixed felix logic also)
    [Enums.py, LimitSwitch.py, Mixus.py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]
2021-03-31 Bug fixing - Linux serial port detection, Popup freezing app, import on windows
    [LimitSwitch.py, Popup.py, SerialCommunication.py]
2021-03-31 Disable buttons if machine in motion + drinkOptionMenu aestethics
2021-04-02 Debug after test on actual machine
    Fixed limitSwitch + set actual slot positions
    [LimitSwitch.py, Mixus.py, Popup.py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]
2021-04-02 Fixed wrong pin for cup switch
    [Enums.py, Mixus.py]
2021-04-05 Multiple fixes with real machines
    [Mixus.py, SerialCommunication.py]
2021-04-06 Added disable button in maintenance menu to disable steppers (to test))
2021-04-08 Update marlin folder
    [Configuration.h, Configuration_adv.h, How to setup Marlin.xlsx]
2021-04-10 Removed obsolete directories
    [Panneau de dessus.STEP, cadre hauteur.STEP, cadre largeur.STEP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]
2021-04-10 Update mechanical doc (commit 1)
    [0,1875x0,5po_Screw.SLDPRT, 6_32_screw.SLDPRT, M2.5x6mm_screw.SLDPRT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]
2021-04-10 Update mechanical doc (commit 2)
    [Frame_Acrylic.SLDPRT, Frame_Acrylic_Left.DXF, Frame_Acrylic_Right.DXF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]
2021-04-10 Update mechanical doc (commit 3)
    [5_to_8_mm_coupler.SLDPRT, 608zz_ball_bearing.SLDPRT, 8mm_leadscrew.SLDPRT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]
2021-04-10 Update mechanical doc (commit 4)
    [0,1875po_Nut.SLDPRT, 40x40x10_DC_Fan.SLDPRT, 6_32_locknut.SLDPRT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]
2021-04-10 Update mechanical doc (commit 5)
    [Drawing_Frame_Acrylic.SLDDRW, Drawing_Frame_Back_Plate.SLDDRW, Drawing_Frame_Side_Plate.SLDDRW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]
2021-04-10 Update mechanical doc (commit 6)
    [2040_Connector_Extrusion.SLDPRT, 2040_Printable_extrusion.SLDPRT, BottleSup_Adapter.SLDPRT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]
2021-04-10 Update mechanical doc (commit 11)
    [SubAss_2040_Extrusion.SLDASM, SubAss_Rambo_Case.SLDASM, SubAss_Removable_Bottle_Support.SLDASM]
2021-04-10 Update mechanical doc (commit 12)
    [SubAss_X_Connector_Plate.SLDASM, SubAss_X_Idler_Plate.SLDASM, SubAss_X_Motor_Plate.SLDASM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]
2021-04-10 Update mechanical doc (commit 13)
    [SubAss_Y_Wheel_Bracket.SLDASM, SubAss_Z_Motor_Bracket.SLDASM, SubAss_Z_Pusher.SLDASM]
2021-04-10 Update mechanical doc (commit 16)
    [SubAss_2040_Extrusion.SLDDRW, SubAss_X_Connector_Plate.SLDDRW, SubAss_X_Idler_Plate.SLDDRW]
2021-04-10 Update mechanical doc (commit 17)
    [SubAss_X_Motor_Plate.SLDDRW, SubAss_Y_Carriage.SLDDRW, SubAss_Y_Wheel_Bracket.SLDDRW]
2021-04-10 Update mechanical doc (commit 18)
    [2040_Connector_Extrusion_M2,5_Slot.STL, 2040_Connector_Extrusion_M3_Slot.STL, 2040_Connector_Extrusion_M3_Top_slot.STL]
2021-04-10 Update mechanical doc (commit 19)
    [2040_Printable_extrusion_side.STL, BottleSup_Adapter.STL]
2021-04-10 Update mechanical doc (commit 20)
    [Frame_Bottom_Center_Beam_Bracket_plexi_side.STL, Frame_Bottom_Center_Beam_Bracket_wood_Side.STL, Frame_Corner_Plexi_Side_Symmetry.STL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]
2021-04-10 Update mechanical doc (commit 21)
    [Frame_Corner_Wood_Side_symmetry.STL, Frame_Top_Center_Beam_Bracket_plexi_side.STL, Frame_Top_Center_Beam_Bracket_wood_side.STL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]
2021-04-10 Update mechanical doc (commit 22)
    [Y_Rail.STL]
2021-04-10 Update mechanical doc (commit 23)
    [Y_Wheel_bracket_default.STL]
2021-04-10 Update mechanical doc (commit 24)
    [Y_Switch_Bracket.STL]
2021-04-10 Update mechanical doc (commit 25)
    [Y_Wheel_bracket_symmetry.STL]
2021-04-10 Added large file using LFS
    [X_Bracket_Wire.STL]
2021-04-10 Added large file using LFS (1)
    [X_Carriage.STL]
2021-04-10 Added large file using LFS (2)
    [Y_Support_rail.STL]
2021-04-10 Added large file using LFS (3)
    [Z_Motor_bracket_Symmetry.STL, Z_Motor_bracket_default.STL]
2021-04-11 Added source to extrusion in bom
    [BOM.xlsx]
2021-04-13 Fixed import error in tests + fullscreen app
    [Mixus.py, PersistenceTest.py, SerialCommunicationTest.py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]

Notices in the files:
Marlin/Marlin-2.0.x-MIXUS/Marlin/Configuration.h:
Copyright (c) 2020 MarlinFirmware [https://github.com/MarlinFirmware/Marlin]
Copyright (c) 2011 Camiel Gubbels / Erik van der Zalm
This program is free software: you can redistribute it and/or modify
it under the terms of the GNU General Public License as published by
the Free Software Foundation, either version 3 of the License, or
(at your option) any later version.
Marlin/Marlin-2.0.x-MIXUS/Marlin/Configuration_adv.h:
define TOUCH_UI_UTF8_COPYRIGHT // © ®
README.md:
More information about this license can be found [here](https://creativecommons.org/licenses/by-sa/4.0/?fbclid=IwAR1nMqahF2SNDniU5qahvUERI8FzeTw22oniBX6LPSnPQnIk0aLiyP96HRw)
